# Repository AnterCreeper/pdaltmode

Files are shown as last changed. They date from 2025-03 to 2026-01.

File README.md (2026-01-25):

# USB PD Alt-mode Host-side Negotiation


If any questions, welcome for Issues & PRs   
如果有疑问，欢迎提交Issues或PR

**WARNING! This Project is not been fully long-term productive tested and without warranty of any kind, use at your own risk!**   
**警告！该项目未经充分的长期生产环境测试，作者不作任何保证，使用需要你自己衡量**

### License

This project is licensed under the LGPL-2.1-or-later license. **DO NOT** download or clone this project until you have read and agree the LICENSE.     
该项目采用 `LGPL-2.1 以及之后版本` 授权。当你下载或克隆项目时，默认已经阅读并同意该协定。

### TODO

1. Active Cable Support (not in plan)
2. Audio Transmission Function Testing

### Overview

This Project is used to perform PD Logic for Host-side based on the cost-effective (30 cents at the time of writing) WCH CH32X035 32-bit RISC-V microcontroller, to achieve DisplayPort output over Type-C, which can be used on space compact scene.    
该项目基于来自 WCH 的低成本 CH32X035 微控制器，包含了所需的所有主机端的 USB Power Delivery 协议的功能，以实现 Type-C 上 DisplayPort 视频输出功能，可用于 PCB 面积紧凑场景。

Besides, This Project include a validation hardware with GERBER and schematics, 4 layers JLC04081H-3313 Stacking, using TOSHIBA TC358867XBG to convert Video stream from Parallel to DisplayPort Signal.   
此外，该项目附有一个验证硬件，包含 GERBER 和原理图与装配图纸，四层 0.8mm JLC04081H-3313 叠层，采用 TOSHIBA TC358867XBG 将 RGB 并行接口 转换至 DisplayPort 信号输出。

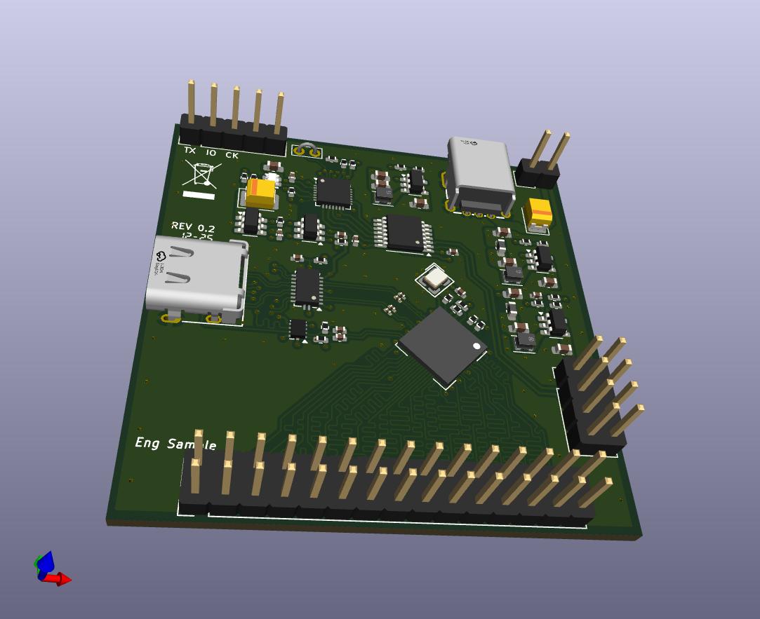
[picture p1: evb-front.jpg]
PCB Preview Picture


This Project implements state machines defined in:
1. Universal Serial Bus Power Delivery Specification Rev 2.0 Ver 1.3
2. Universal Serial Bus Type-C Cable and Connector Specification Ver 2.2.
3. VESA DisplayPort Alt Mode on USB Type-C Standard. Ver 1.3/1.4.
4. VESA DisplayPort Standard. Version 1, Revision 2.

Doc. 1 and 2 can be accessed from https://github.com/usb-c/USB-Type-C   
For Doc. 3, since **DISTRIBUTION TO NON-MEMBERS IS PROHIBITED**, contact me at [wangzhihao9@hotmail.com](mailto:wangzhihao9@hotmail.com)  
Doc.4 is located at https://glenwing.github.io/docs/DP-1.2.pdf

Datasheet of TC358867XBG is included in the project, which includes external LICENSE.

Some other Specification related to Audio which is needed: (May have copies over web.archive.org)
1. [CEA 861-E](https://members.cta.tech/ctaPublicationDetails/?id=95190170-1031-e811-bbd4-0003ff52999d): A DTV Profile for Uncompressed High Speed Digital Interfaces
2. [IEC60958](https://webstore.iec.ch/en/publication/62829): Digital Audio Interfaces

### Usage

1. Download and Open with MounRiver Studio II [Download Page](http://www.mounriver.com/download)
2. Connect the board with WCH Link-E, then Compile and Run
3. ~~Files except in User is remain unchanged from default.~~

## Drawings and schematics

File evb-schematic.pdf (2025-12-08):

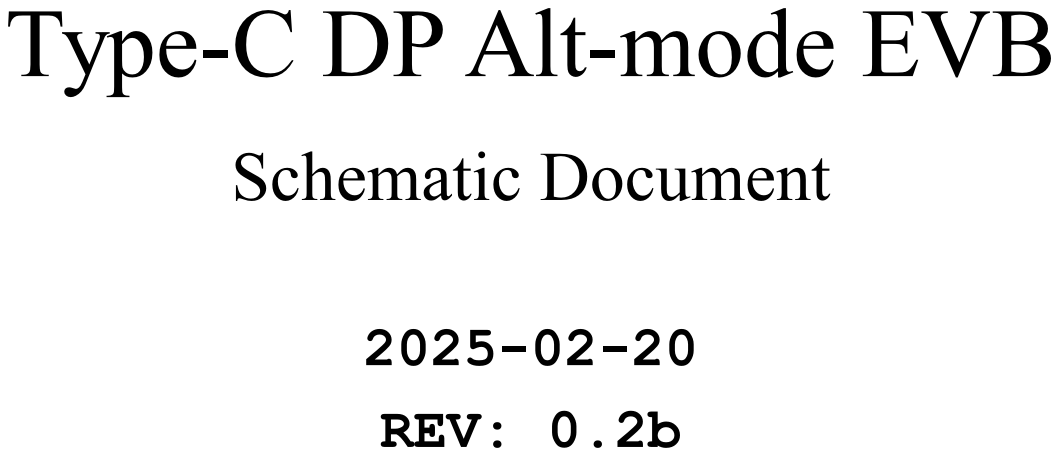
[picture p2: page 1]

Id: 1/5 Title: File: cover.kicad_sch Sheet: /COVER/ Type-CDPAlt-modeEVB
SchematicDocument

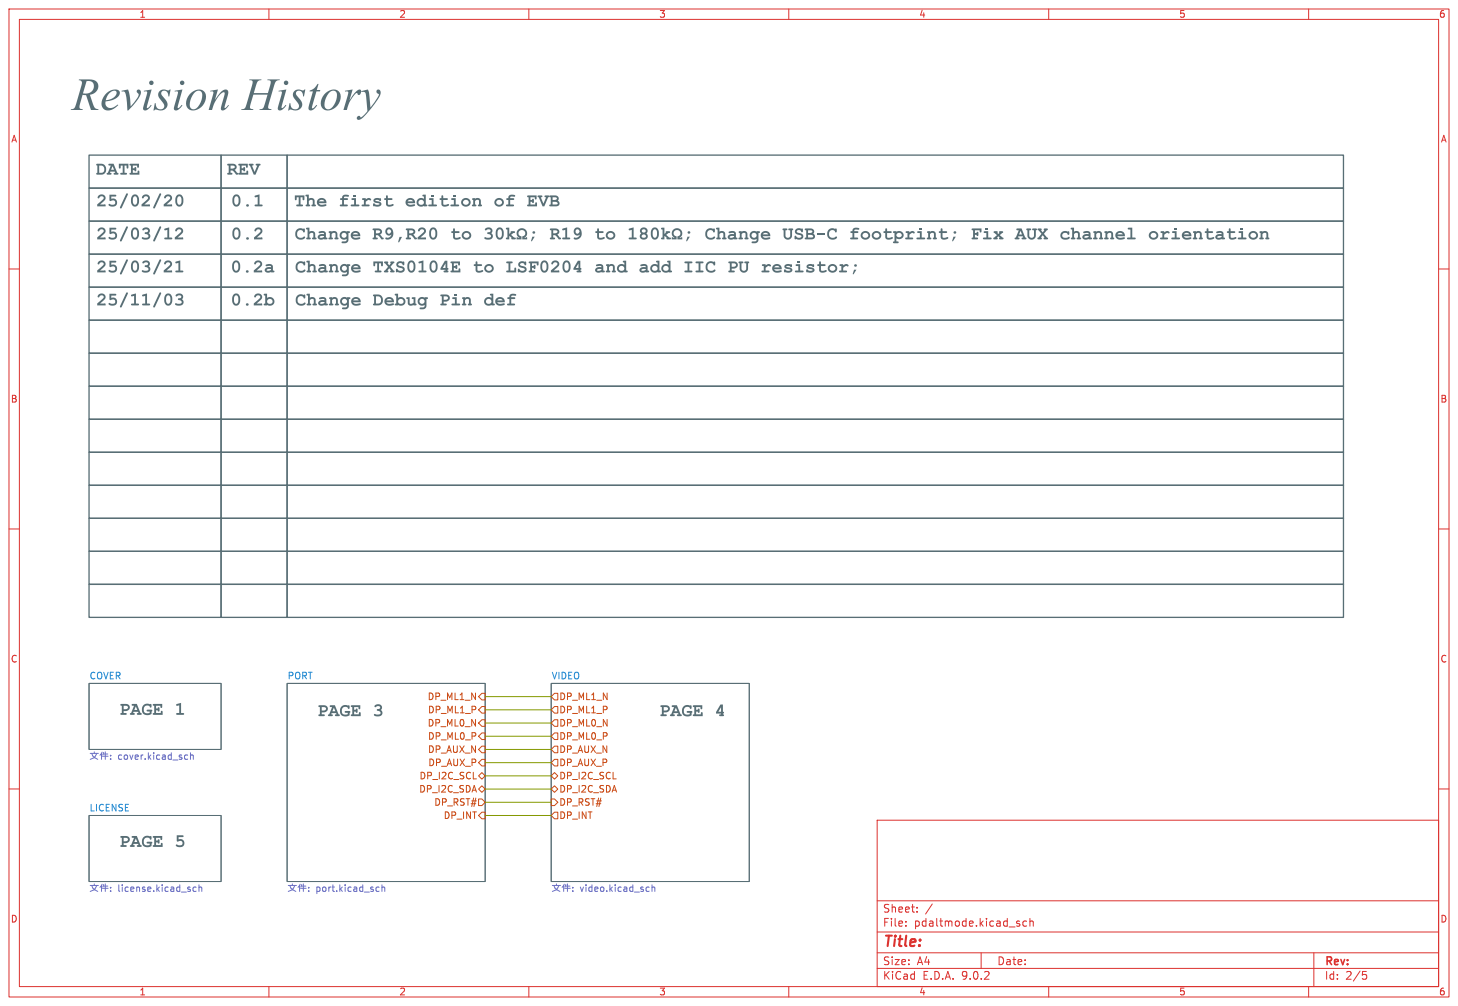
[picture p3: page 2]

DATE | REV
25/02/20 | 0.1 | The first edition of EVB
25/03/12 | 0.2 | Change R9,R20 to þÿ30k©; R19 to þÿ180k©; Change USB-C footprint; Fix AUX channel orientation
25/03/21 | 0.2a | Change TXS0104E to LSF0204 and add IIC PU resistor;
25/11/03 | 0.2b | Change Debug Pin def

þÿe‡Nö: license.kicad_sch COVER
PAGE 1

Id: 2/5 Title: File: pdaltmode.kicad_sch Sheet: / LICENSE
PAGE 5

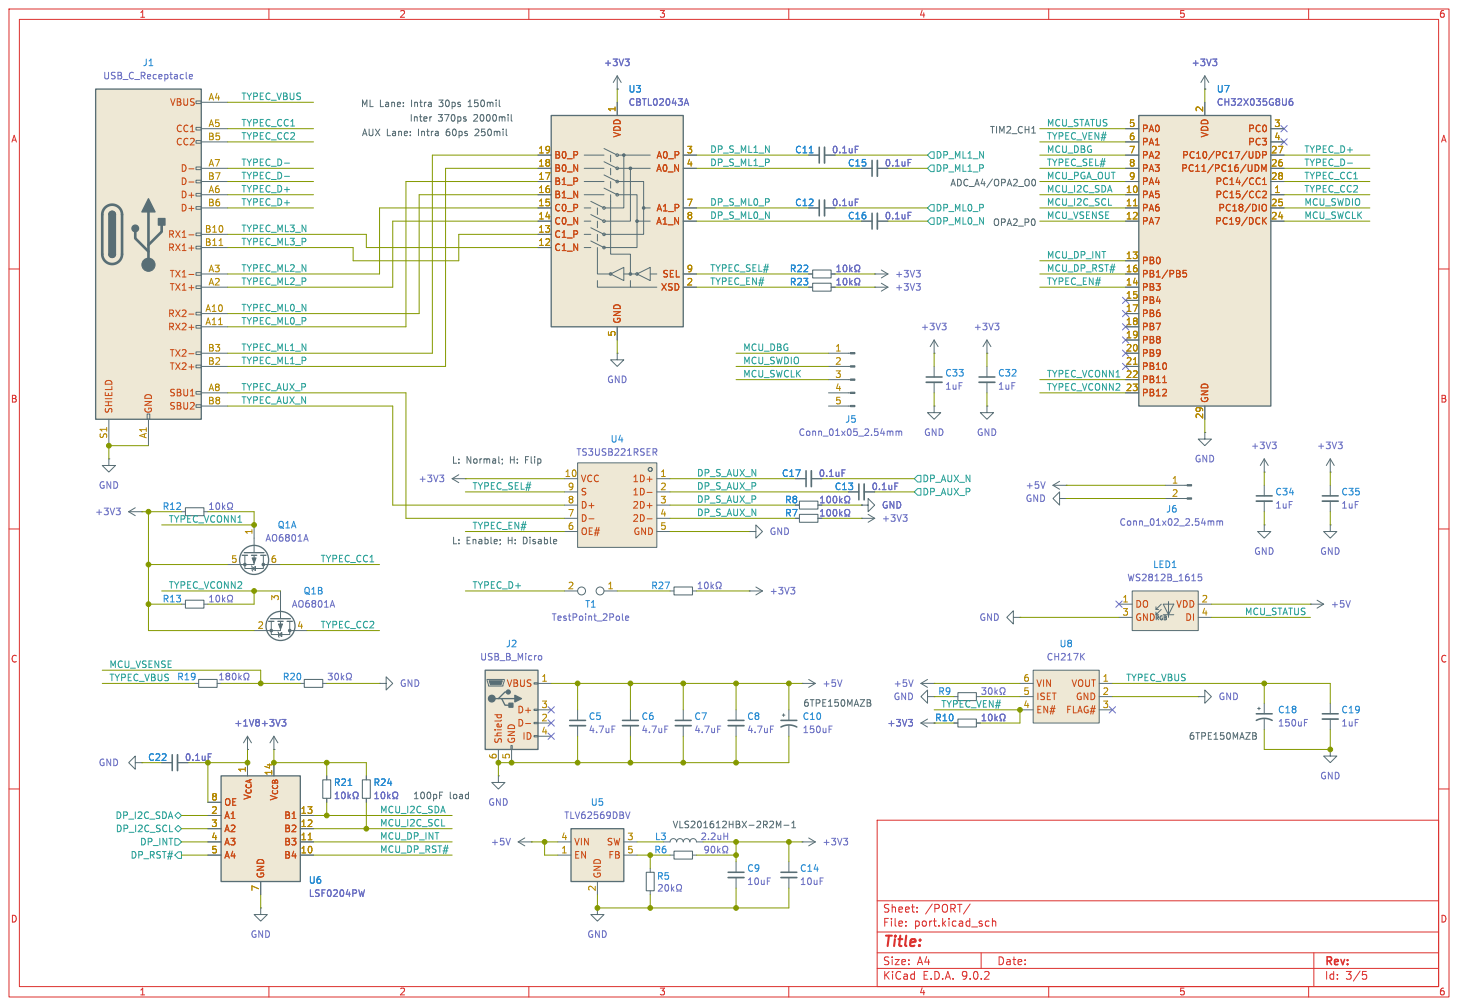
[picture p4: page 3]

L: Enable; H: Disable ML Lane: Intra 30ps 150mil Inter 370ps 2000mil AUX Lane: Intra 60ps 250mil L: Normal; H: Flip

2 GND 29 PC0 3 PC3 4 PC10/PC17/UDP 27 PC11/PC16/UDM 26 PC14/CC1 28 PC15/CC2 1 PC18/DIO 25 PC19/DCK 24 PB1/PB5 16 +3V3 R10 þÿ10k©

2 GND 29 PC0 3 PC3 4 PC10/PC17/UDP 27 PC11/PC16/UDM 26 PC14/CC1 28 PC15/CC2 1 PC18/DIO 25 PC19/DCK 24 PB1/PB5 16 U7 CH32X035G8U6

2 SW 3 FB 5 U5 TLV62569DBV R13 þÿ10k© GND

6TPE150MAZB
Id: 3/5 Title: File: port.kicad_sch Sheet: /PORT/ C10

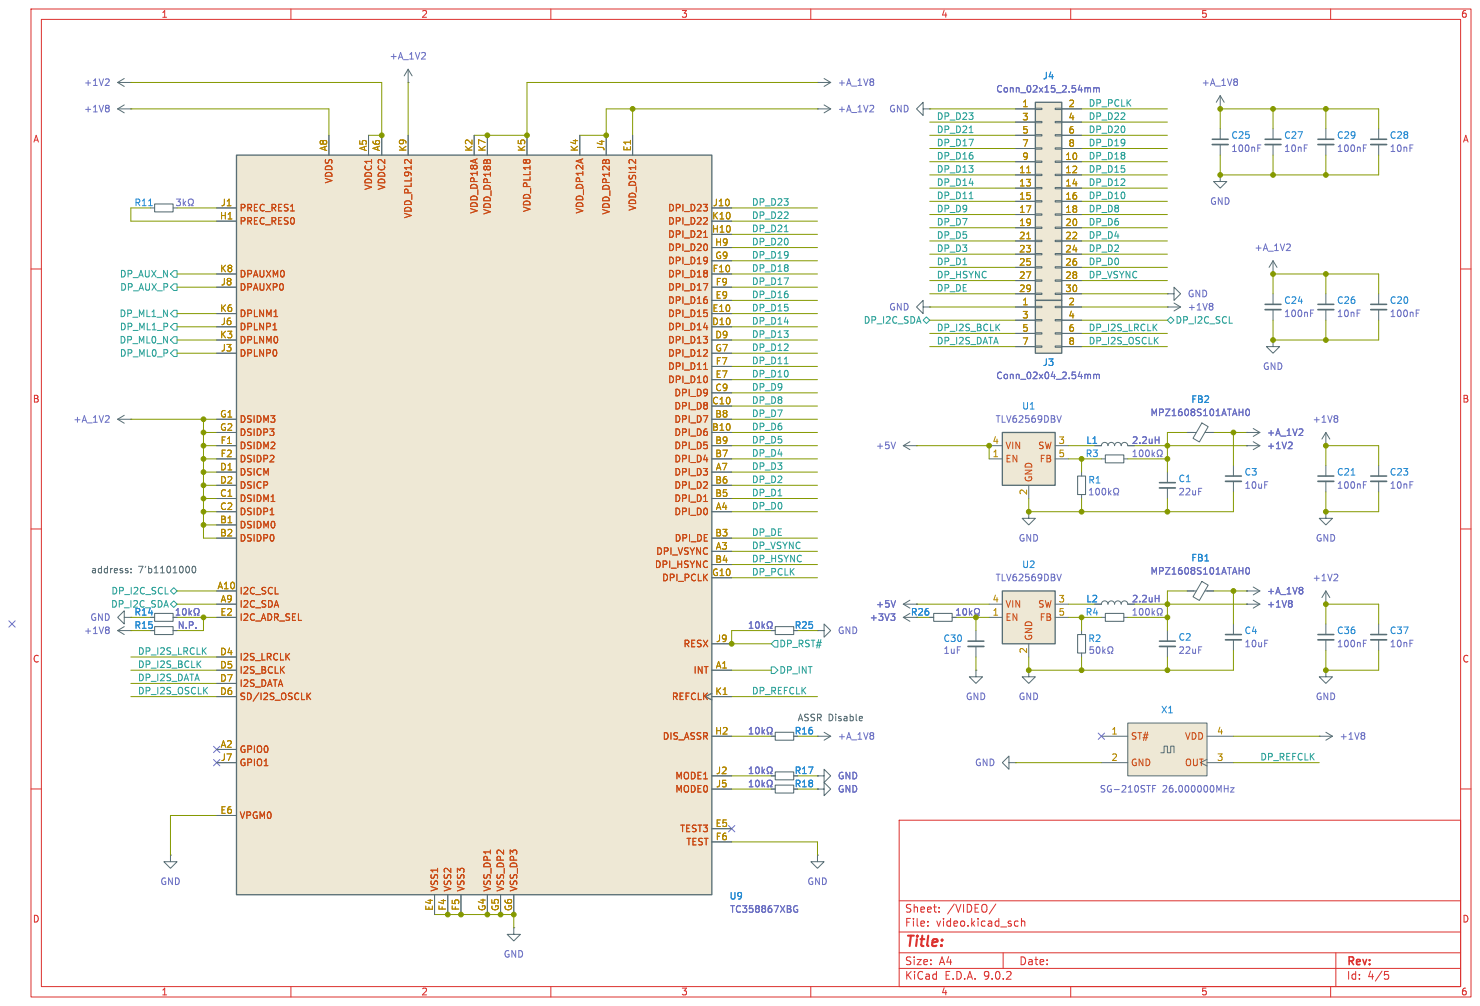
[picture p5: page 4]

2 SW 3 FB 5 U2 TLV62569DBV GND GND

Id: 4/5 Title: File: video.kicad_sch Sheet: /VIDEO/

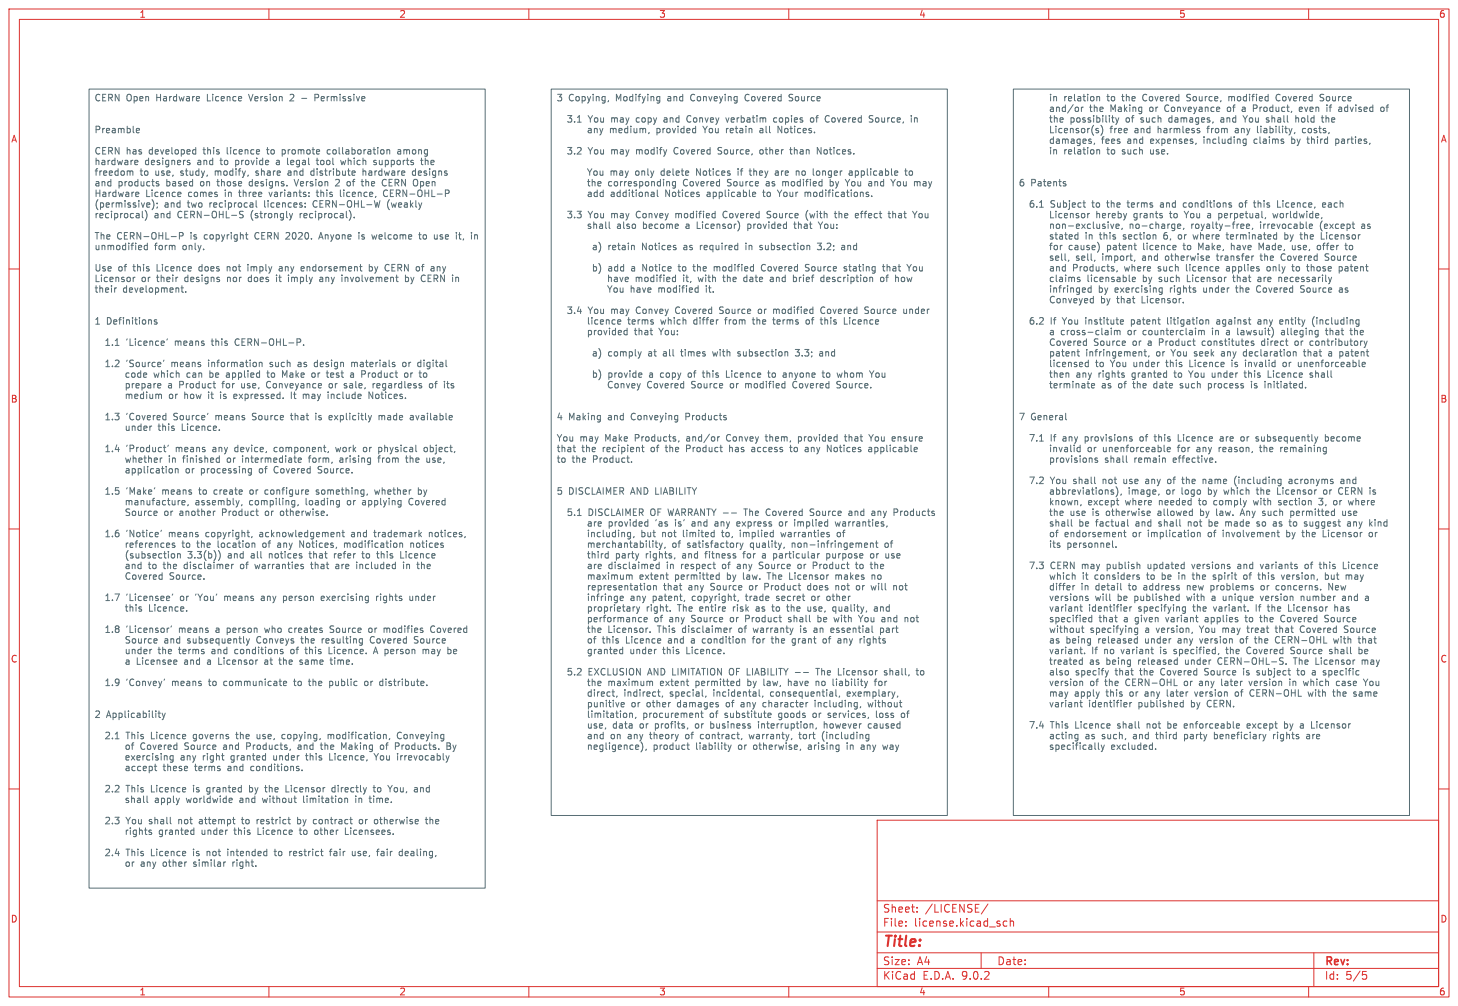
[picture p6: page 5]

for cause) patent licence to Make, have Made, use, offer to

licence terms which differ from the terms of this Licence

to the Product. 5 DISCLAIMER AND LIABILITY

known, except where needed to comply with section 3, or where

version of the CERN-OHL or any later version in which case You may apply this or any later version of CERN-OHL with the same

Id: 5/5 Title: File: license.kicad_sch Sheet: /LICENSE/

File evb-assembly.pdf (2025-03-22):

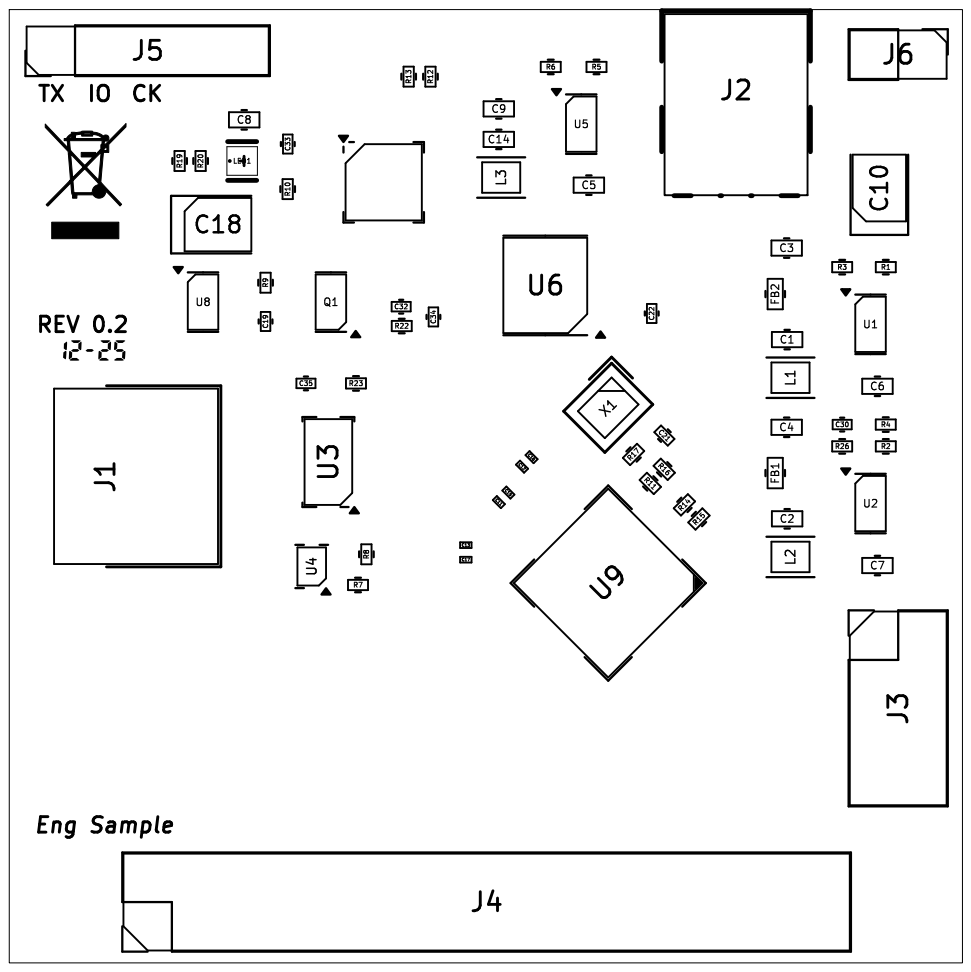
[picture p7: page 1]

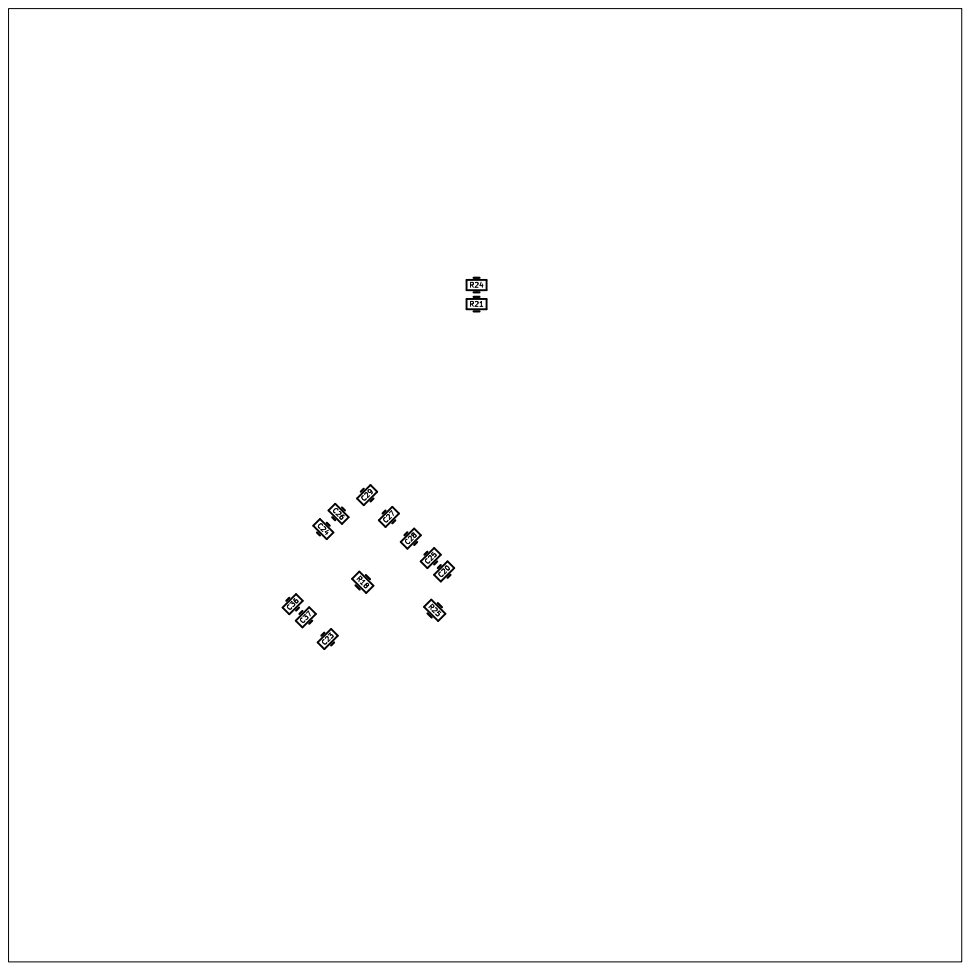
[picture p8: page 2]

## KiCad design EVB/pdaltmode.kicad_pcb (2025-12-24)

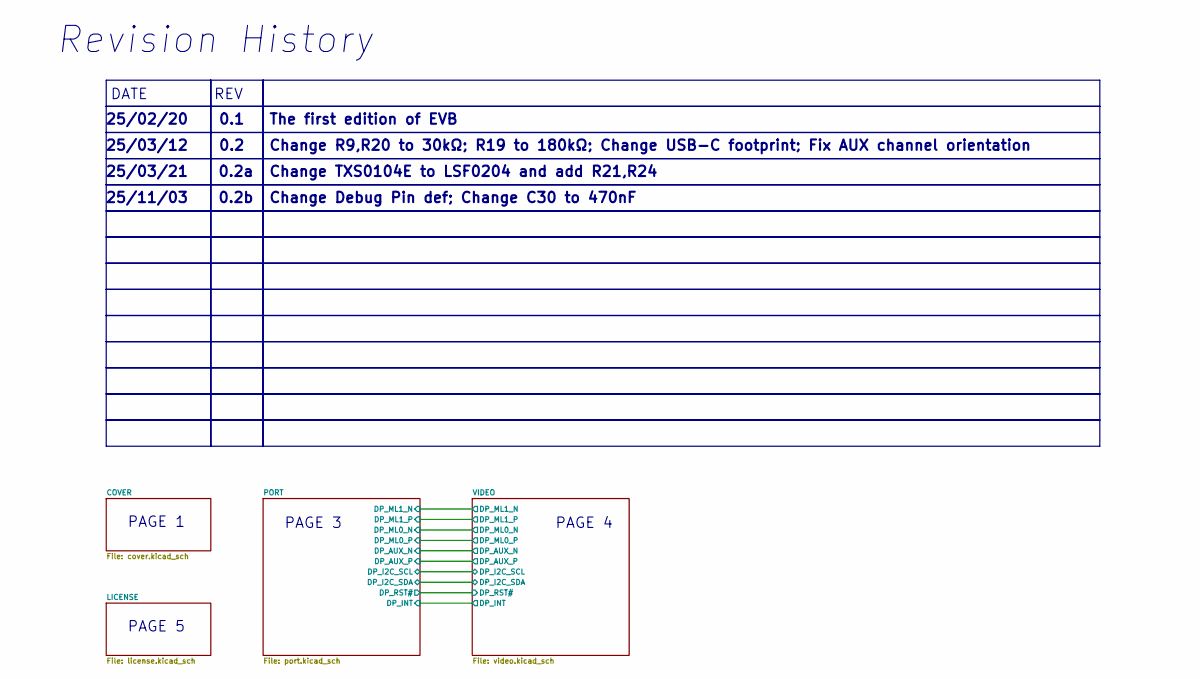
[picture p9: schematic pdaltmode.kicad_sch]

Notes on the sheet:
Change Debug Pin def; Change C30 to 470nF
Change TXS0104E to LSF0204 and add R21,R24
PAGE 5
25/11/03
PAGE 3
PAGE 1
0.2b
Change R9,R20 to 30kΩ; R19 to 180kΩ; Change USB-C footprint; Fix AUX channel orientation
0.1
Revision History
The first edition of EVB
DATE
25/03/12
0.2a
0.2
25/03/21
PAGE 4
REV
25/02/20

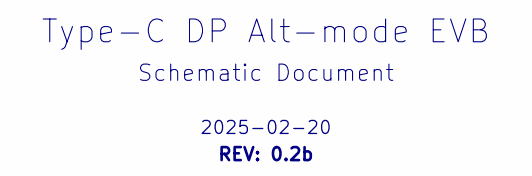
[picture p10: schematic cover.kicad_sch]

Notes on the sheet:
REV: 0.2b
2025-02-20
Type-C DP Alt-mode EVB
Schematic Document

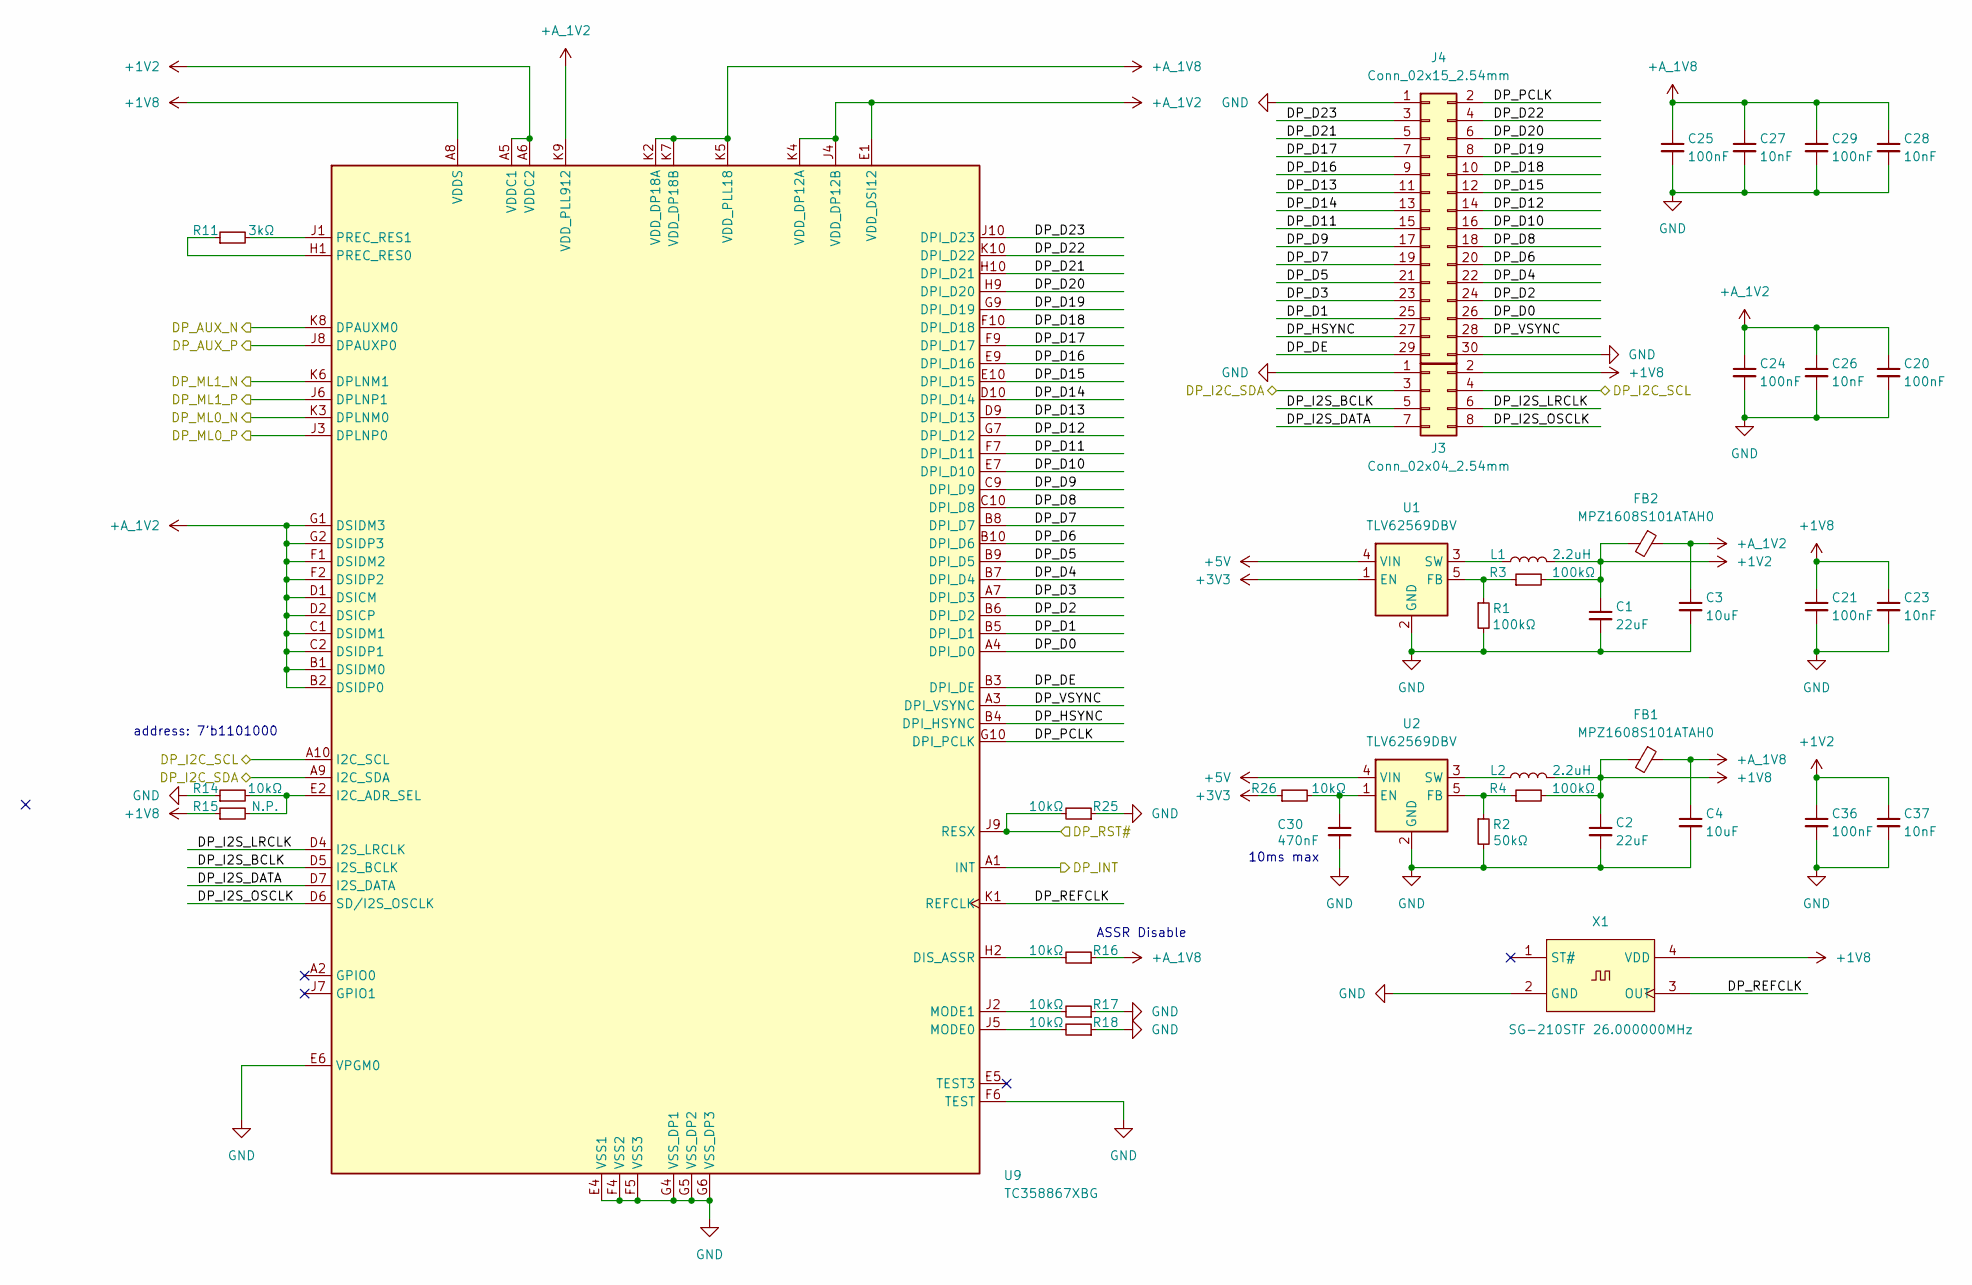
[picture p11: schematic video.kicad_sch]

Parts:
C1, C2: 22uF; C_0603_1608Metric
C3, C4: 10uF; C_0603_1608Metric
C20, C21, C24, C25, C29, C36: 100nF; C_0402_1005Metric
C23, C26, C27, C28, C37: 10nF; C_0402_1005Metric
C30: 470nF; C_0402_1005Metric
FB1, FB2: MPZ1608S101ATAH0; L_0603_1608Metric
J3: Conn_02x04_2.54mm; PinHeader_2x04_P2.54mm_Vertical
J4: Conn_02x15_2.54mm; PinHeader_2x15_P2.54mm_Vertical
L1, L2: 2.2uH; L_Murata_DFE201610P
R1, R3, R4: 100kΩ; R_0402_1005Metric
R2: 50kΩ; R_0402_1005Metric
R11: 3kΩ; R_0402_1005Metric
R14, R16, R17, R18, R25, R26: 10kΩ; R_0402_1005Metric
R15: N.P.; R_0402_1005Metric
U1, U2: TLV62569DBV; SOT-23-5
U9: TC358867XBG; Toshiba_VFBGA-80_7.0x7.0mm
X1: SG-210STF 26.000000MHz; Oscillator_SMD_SeikoEpson_SG210-4Pin_2.5x2.0mm

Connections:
+1V2: C1.1, C36.1, C37.1, FB2.2, L1.2, R3.2, U9.A5 (VDDC1), U9.A6 (VDDC2)
+1V8: C2.1, C21.1, C23.1, FB1.2, J3.2, L2.2, R4.2, R15.1, U9.A8 (VDDS), X1.4 (VDD); also elsewhere on the board
+3V3: R26.1, U1.1 (EN); also elsewhere on the board
+5V: U1.4 (VIN), U2.4 (VIN); also elsewhere on the board
+A_1V2: C3.1, C20.1, C24.1, C26.1, FB2.1, U9.B1 (DSIDM0), U9.B2 (DSIDP0), U9.C1 (DSIDM1), U9.C2 (DSIDP1), U9.D1 (DSICM), U9.D2 (DSICP), U9.E1 (VDD_DSI12), U9.F1 (DSIDM2), U9.F2 (DSIDP2), U9.G1 (DSIDM3), U9.G2 (DSIDP3), U9.J4 (VDD_DP12B), U9.K4 (VDD_DP12A), U9.K9 (VDD_PLL912)
+A_1V8: C4.1, C25.1, C27.1, C28.1, C29.1, FB1.1, R16.1, U9.K2 (VDD_DP18A), U9.K5 (VDD_PLL18), U9.K7 (VDD_DP18B)
/PORT/DP_AUX_N: U9.K8 (DPAUXM0); also elsewhere on the board
/PORT/DP_AUX_P: U9.J8 (DPAUXP0); also elsewhere on the board
/PORT/DP_I2C_SCL: J3.4, U9.A10 (I2C_SCL); also elsewhere on the board
/PORT/DP_I2C_SDA: J3.3, U9.A9 (I2C_SDA); also elsewhere on the board
/PORT/DP_INT: U9.A1 (INT); also elsewhere on the board
/PORT/DP_ML0_N: U9.K3 (DPLNM0); also elsewhere on the board
/PORT/DP_ML0_P: U9.J3 (DPLNP0); also elsewhere on the board
/PORT/DP_ML1_N: U9.K6 (DPLNM1); also elsewhere on the board
/PORT/DP_ML1_P: U9.J6 (DPLNP1); also elsewhere on the board
/PORT/DP_RST#: R25.2, U9.J9 (RESX); also elsewhere on the board
/VIDEO/DP_D0: J4.26, U9.A4 (DPI_D0)
/VIDEO/DP_D1: J4.25, U9.B5 (DPI_D1)
/VIDEO/DP_D2: J4.24, U9.B6 (DPI_D2)
/VIDEO/DP_D3: J4.23, U9.A7 (DPI_D3)
/VIDEO/DP_D4: J4.22, U9.B7 (DPI_D4)
/VIDEO/DP_D5: J4.21, U9.B9 (DPI_D5)
/VIDEO/DP_D6: J4.20, U9.B10 (DPI_D6)
/VIDEO/DP_D7: J4.19, U9.B8 (DPI_D7)
/VIDEO/DP_D8: J4.18, U9.C10 (DPI_D8)
/VIDEO/DP_D9: J4.17, U9.C9 (DPI_D9)
/VIDEO/DP_D10: J4.16, U9.E7 (DPI_D10)
/VIDEO/DP_D11: J4.15, U9.F7 (DPI_D11)
/VIDEO/DP_D12: J4.14, U9.G7 (DPI_D12)
/VIDEO/DP_D13: J4.11, U9.D9 (DPI_D13)
/VIDEO/DP_D14: J4.13, U9.D10 (DPI_D14)
/VIDEO/DP_D15: J4.12, U9.E10 (DPI_D15)
/VIDEO/DP_D16: J4.9, U9.E9 (DPI_D16)
/VIDEO/DP_D17: J4.7, U9.F9 (DPI_D17)
/VIDEO/DP_D18: J4.10, U9.F10 (DPI_D18)
/VIDEO/DP_D19: J4.8, U9.G9 (DPI_D19)
/VIDEO/DP_D20: J4.6, U9.H9 (DPI_D20)
/VIDEO/DP_D21: J4.5, U9.H10 (DPI_D21)
/VIDEO/DP_D22: J4.4, U9.K10 (DPI_D22)
/VIDEO/DP_D23: J4.3, U9.J10 (DPI_D23)
/VIDEO/DP_DE: J4.29, U9.B3 (DPI_DE)
/VIDEO/DP_HSYNC: J4.27, U9.B4 (DPI_HSYNC)
/VIDEO/DP_I2S_BCLK: J3.5, U9.D5 (I2S_BCLK)
/VIDEO/DP_I2S_DATA: J3.7, U9.D7 (I2S_DATA)
/VIDEO/DP_I2S_LRCLK: J3.6, U9.D4 (I2S_LRCLK)
/VIDEO/DP_I2S_OSCLK: J3.8, U9.D6 (SD/I2S_OSCLK)
/VIDEO/DP_PCLK: J4.2, U9.G10 (DPI_PCLK)
/VIDEO/DP_REFCLK: U9.K1 (REFCLK), X1.3 (OUT)
/VIDEO/DP_VSYNC: J4.28, U9.A3 (DPI_VSYNC)
GND: C1.2, C2.2, C3.2, C4.2, C20.2, C21.2, C23.2, C24.2, C25.2, C26.2, C27.2, C28.2, C29.2, C30.2, C36.2, C37.2, J3.1, J4.1, J4.30, R1.2, R2.2, R14.1, R17.1, R18.1, R25.1, U1.2 (GND), U2.2 (GND), U9.E4 (VSS1), U9.E6 (VPGM0), U9.F4 (VSS2), U9.F5 (VSS3), U9.F6 (TEST), U9.G4 (VSS_DP1), U9.G5 (VSS_DP2), U9.G6 (VSS_DP3), X1.2 (GND); also elsewhere on the board
unnamed: R1.1, R3.1, U1.5 (FB)
unnamed: L1.1, U1.3 (SW)
unnamed: C30.1, R26.2, U2.1 (EN)
unnamed: R2.1, R4.1, U2.5 (FB)
unnamed: L2.1, U2.3 (SW)
unnamed: R16.2, U9.H2 (DIS_ASSR)
unnamed: R14.2, R15.2, U9.E2 (I2C_ADR_SEL)
unnamed: R18.2, U9.J5 (MODE0)
unnamed: R17.2, U9.J2 (MODE1)
unnamed: R11.1, U9.H1 (PREC_RES0)
unnamed: R11.2, U9.J1 (PREC_RES1)

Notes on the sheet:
ASSR Disable
10ms max
address: 7'b1101000

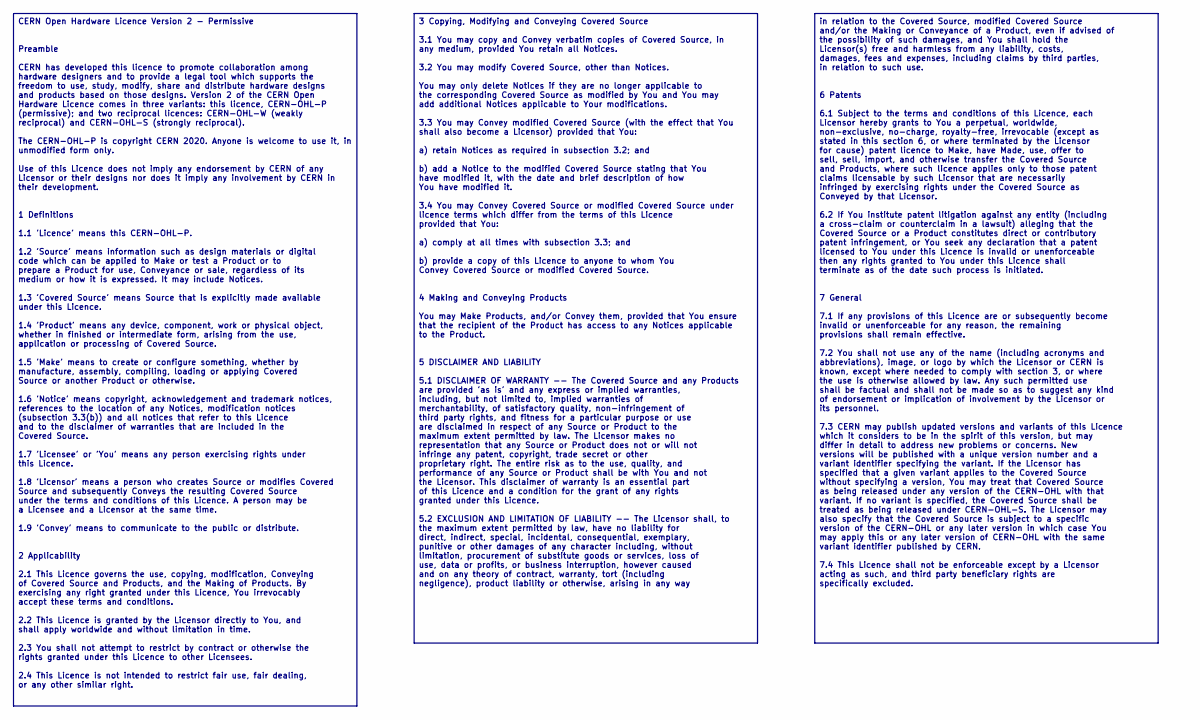
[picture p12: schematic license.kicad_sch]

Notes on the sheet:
3 Copying, Modifying and Conveying Covered Source 3.1 You may copy and Convey verbatim copies of Covered Source, in any medium, provided You retain all Notices. 3.2 You may modify Covered Source, other than Notices. You may only delete Notices if they are no longer applicable to the corresponding C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
CERN Open Hardware Licence Version 2 - Permissive Preamble CERN has developed this licence to promote collaboration among hardware designers and to provide a legal tool which supports the freedom to use, study, modify, share and distribute hardware designs and products based on those designs. Versi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
in relation to the Covered Source, modified Covered Source and/or the Making or Conveyance of a Product, even if advised of the possibility of such damages, and You shall hold the Licensor(s) free and harmless from any liability, costs, damages, fees and expenses, including claims by third parties,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

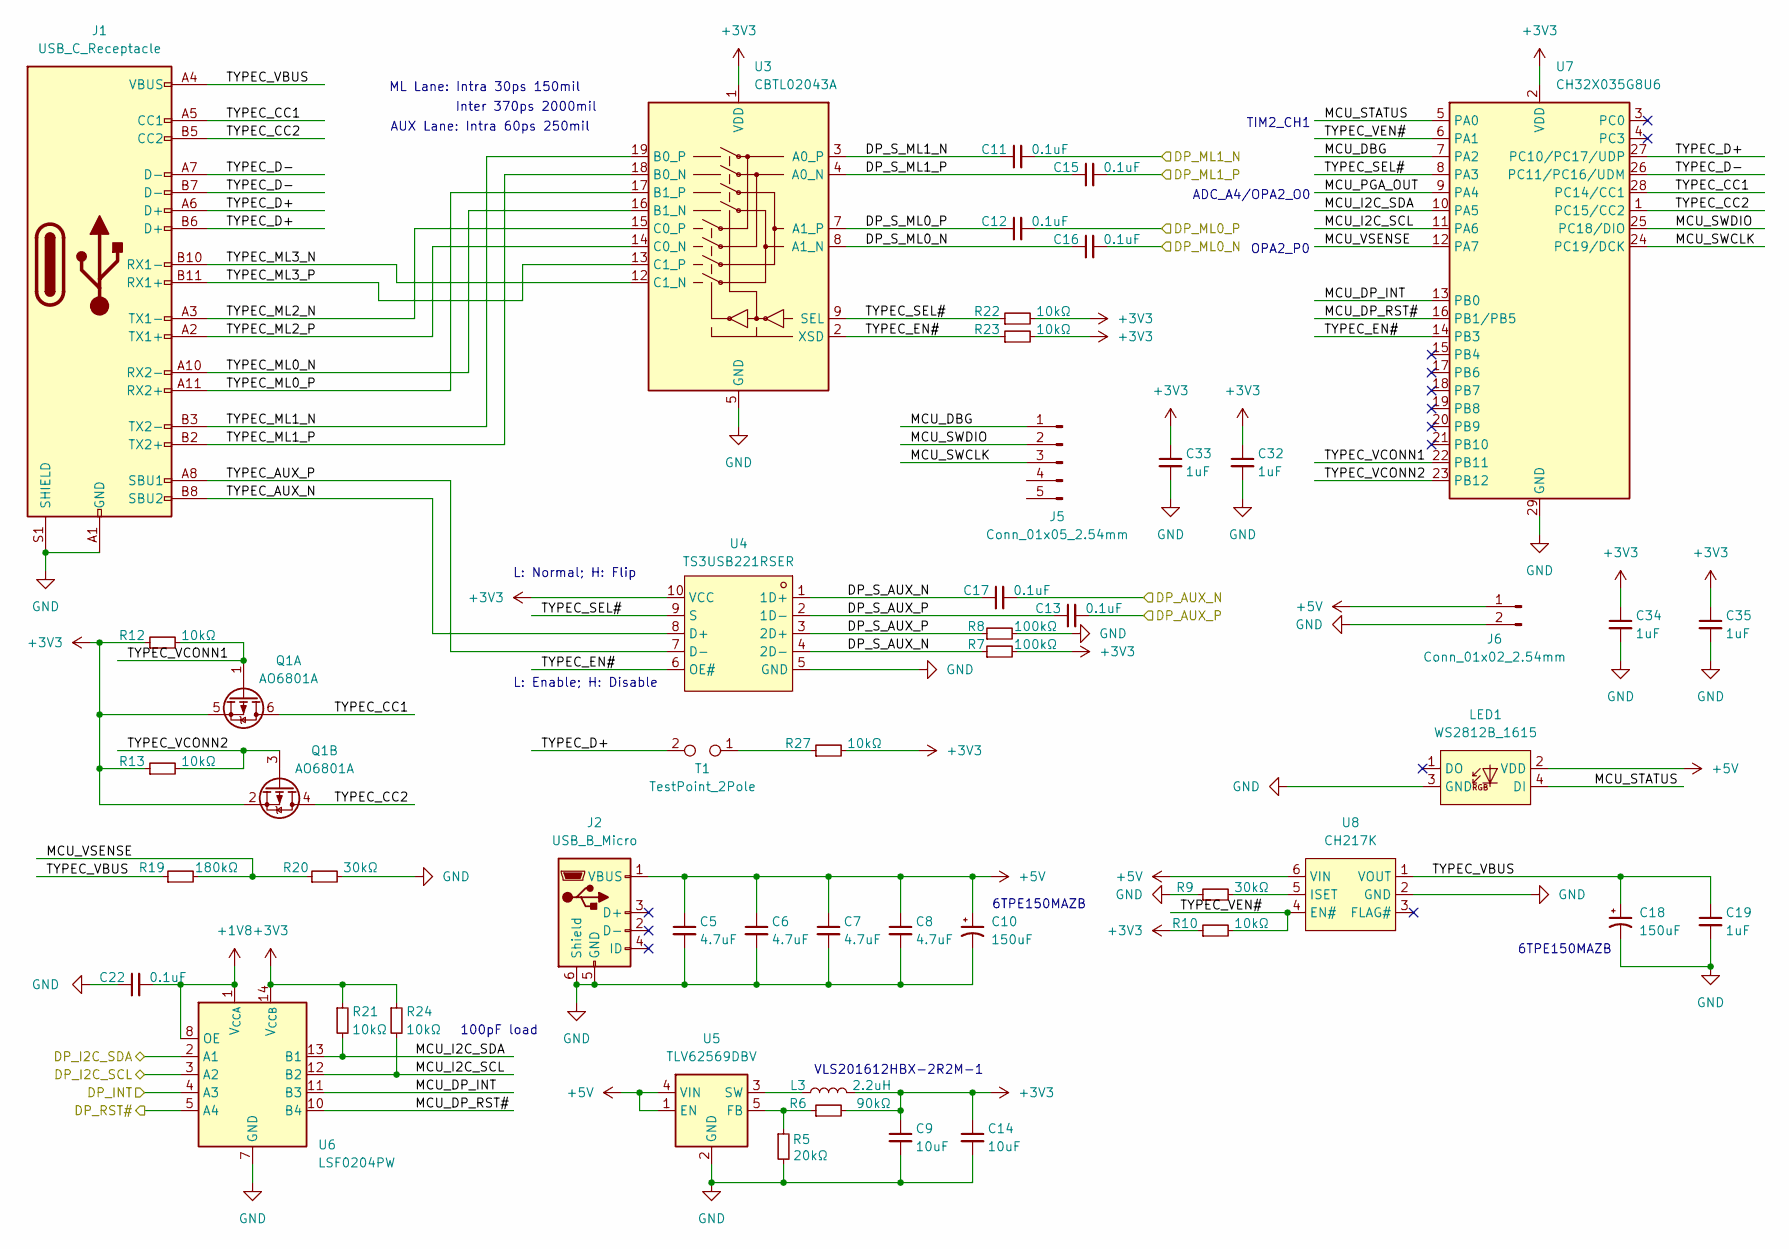
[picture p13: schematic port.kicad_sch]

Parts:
C5, C6, C7, C8: 4.7uF; C_0603_1608Metric
C9, C14: 10uF; C_0603_1608Metric
C10, C18: 150uF; CP_EIA-3528-21_Kemet-B
C11, C12, C15, C16: 0.1uF; C_0201_0603Metric
C13, C17, C22: 0.1uF; C_0402_1005Metric
C19, C32, C33, C34, C35: 1uF; C_0402_1005Metric
J1: USB_C_Receptacle; USB_C_Receptacle_Amphenol_10137062-00021LF
J2: USB_B_Micro; USB_Mini-B_Wuerth_651005136521
J5: Conn_01x05_2.54mm; PinHeader_1x05_P2.54mm_Vertical
J6: Conn_01x02_2.54mm; PinHeader_1x02_P2.54mm_Vertical
L3: 2.2uH; L_Murata_DFE201610P
LED1: WS2812B_1615; LED_WS2812B-1615_SMD-4P_1.6x1.5mm; LCSC Part Name XL-1615RGBC-WS2812B-S
Q1: AO6801A; SOT-23-6
R5: 20kΩ; R_0402_1005Metric
R6: 90kΩ; R_0402_1005Metric
R7, R8: 100kΩ; R_0402_1005Metric
R9, R20: 30kΩ; R_0402_1005Metric
R10, R12, R13, R21, R22, R23, R24, R27: 10kΩ; R_0402_1005Metric
R19: 180kΩ; R_0402_1005Metric
T1: TestPoint_2Pole; TestPoint_Bridge_Pitch2.0mm_Drill0.7mm
U3: CBTL02043A; WQFN-20-1EP_2.5x4.5mm_P0.5mm_EP1x2.9mm
U4: TS3USB221RSER; Texas_UQFN-10_1.5x2mm_P0.5mm
U5: TLV62569DBV; SOT-23-5
U6: LSF0204PW; TSSOP-14_4.4x5mm_P0.65mm
U7: CH32X035G8U6; QFN-28-1EP_4x4mm_P0.4mm_EP2.7x2.7mm
U8: CH217K; SOT-23-6

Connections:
+1V8: C22.2, U6.1 (V_{CCA}), U6.8 (OE); also elsewhere on the board
+3V3: C9.1, C14.1, C32.1, C33.1, C34.1, C35.1, L3.2, Q1.2 (S), Q1.5 (S), R6.2, R7.2, R10.1, R12.1, R13.1, R21.1, R22.2, R23.2, R24.1, R27.2, U3.1 (VDD), U3.6 (VDD), U3.10 (VDD), U4.10 (VCC), U6.14 (V_{CCB}), U7.2 (VDD); also elsewhere on the board
+5V: C5.1, C6.1, C7.1, C8.1, C10.1, J2.1 (VBUS), J6.1, LED1.2 (VDD), U5.1 (EN), U5.4 (VIN), U8.6 (VIN); also elsewhere on the board
/PORT/DP_AUX_N: C17.2; also elsewhere on the board
/PORT/DP_AUX_P: C13.2; also elsewhere on the board
/PORT/DP_I2C_SCL: U6.3 (A2); also elsewhere on the board
/PORT/DP_I2C_SDA: U6.2 (A1); also elsewhere on the board
/PORT/DP_INT: U6.4 (A3); also elsewhere on the board
/PORT/DP_ML0_N: C16.2; also elsewhere on the board
/PORT/DP_ML0_P: C12.2; also elsewhere on the board
/PORT/DP_ML1_N: C11.2; also elsewhere on the board
/PORT/DP_ML1_P: C15.2; also elsewhere on the board
/PORT/DP_RST#: U6.5 (A4); also elsewhere on the board
/PORT/DP_S_AUX_N: C17.1, R7.1, U4.1 (1D+), U4.4 (2D-)
/PORT/DP_S_AUX_P: C13.1, R8.1, U4.2 (1D-), U4.3 (2D+)
/PORT/DP_S_ML0_N: C16.1, U3.8 (A1_N)
/PORT/DP_S_ML0_P: C12.1, U3.7 (A1_P)
/PORT/DP_S_ML1_N: C11.1, U3.3 (A0_P)
/PORT/DP_S_ML1_P: C15.1, U3.4 (A0_N)
/PORT/MCU_DBG: J5.1, U7.7 (PA2)
/PORT/MCU_DP_INT: U6.11 (B3), U7.13 (PB0)
/PORT/MCU_DP_RST#: U6.10 (B4), U7.16 (PB1/PB5)
/PORT/MCU_I2C_SCL: R24.2, U6.12 (B2), U7.11 (PA6)
/PORT/MCU_I2C_SDA: R21.2, U6.13 (B1), U7.10 (PA5)
/PORT/MCU_PGA_OUT: U7.9 (PA4)
/PORT/MCU_STATUS: LED1.4 (DI), U7.5 (PA0)
/PORT/MCU_SWCLK: J5.3, U7.24 (PC19/DCK)
/PORT/MCU_SWDIO: J5.2, U7.25 (PC18/DIO)
/PORT/MCU_VSENSE: R19.2, R20.1, U7.12 (PA7)
/PORT/TYPEC_AUX_N: J1.B8 (SBU2), U4.8 (D+)
/PORT/TYPEC_AUX_P: J1.A8 (SBU1), U4.7 (D-)
/PORT/TYPEC_CC1: J1.A5 (CC1), Q1.6 (D), U7.28 (PC14/CC1)
/PORT/TYPEC_CC2: J1.B5 (CC2), Q1.4 (D), U7.1 (PC15/CC2)
/PORT/TYPEC_D+: J1.A6 (D+), J1.B6 (D+), T1.2, U7.27 (PC10/PC17/UDP)
/PORT/TYPEC_D-: J1.A7 (D-), J1.B7 (D-), U7.26 (PC11/PC16/UDM)
/PORT/TYPEC_EN#: R23.1, U3.2 (XSD), U4.6 (OE#), U7.14 (PB3)
/PORT/TYPEC_ML0_N: J1.A10 (RX2-), U3.16 (B1_N)
/PORT/TYPEC_ML0_P: J1.A11 (RX2+), U3.17 (B1_P)
/PORT/TYPEC_ML1_N: J1.B3 (TX2-), U3.19 (B0_P)
/PORT/TYPEC_ML1_P: J1.B2 (TX2+), U3.18 (B0_N)
/PORT/TYPEC_ML2_N: J1.A3 (TX1-), U3.15 (C0_P)
/PORT/TYPEC_ML2_P: J1.A2 (TX1+), U3.14 (C0_N)
/PORT/TYPEC_ML3_N: J1.B10 (RX1-), U3.12 (C1_N)
/PORT/TYPEC_ML3_P: J1.B11 (RX1+), U3.13 (C1_P)
/PORT/TYPEC_SEL#: R22.1, U3.9 (SEL), U4.9 (S), U7.8 (PA3)
/PORT/TYPEC_VBUS: C18.1, C19.1, J1.A4 (VBUS), J1.A9 (VBUS), J1.B4 (VBUS), J1.B9 (VBUS), R19.1, U8.1 (VOUT)
/PORT/TYPEC_VCONN1: Q1.1 (G), R12.2, U7.22 (PB11)
/PORT/TYPEC_VCONN2: Q1.3 (G), R13.2, U7.23 (PB12)
/PORT/TYPEC_VEN#: R10.2, U7.6 (PA1), U8.4 (EN#)
GND: C5.2, C6.2, C7.2, C8.2, C9.2, C10.2, C14.2, C18.2, C19.2, C22.1, C32.2, C33.2, C34.2, C35.2, J1.A1 (GND), J1.A12 (GND), J1.B1 (GND), J1.B12 (GND), J1.S1 (SHIELD), J2.5 (GND), J2.6 (Shield), J6.2, LED1.3 (GND), R5.2, R8.2, R9.1, R20.2, U3.5 (GND), U3.11 (GND), U3.20 (GND), U3.21 (GND), U4.5 (GND), U5.2 (GND), U6.7 (GND), U7.29 (GND), U8.2 (GND); also elsewhere on the board
unnamed: R27.1, T1.1
unnamed: R5.1, R6.1, U5.5 (FB)
unnamed: L3.1, U5.3 (SW)
unnamed: R9.2, U8.5 (ISET)

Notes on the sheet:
TIM2_CH1
6TPE150MAZB
AUX Lane: Intra 60ps 250mil
VLS201612HBX-2R2M-1
Inter 370ps 2000mil
OPA2_P0
100pF load
L: Enable; H: Disable
ADC_A4/OPA2_O0
ML Lane: Intra 30ps 150mil
L: Normal; H: Flip

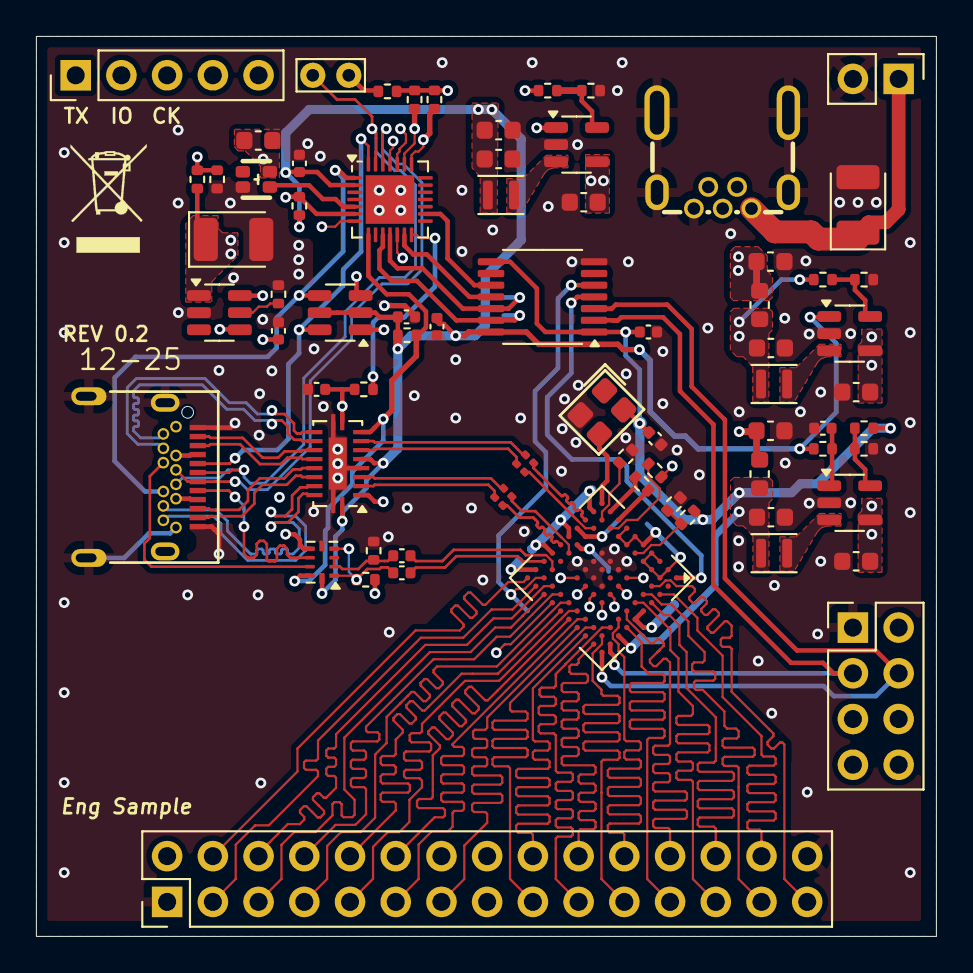
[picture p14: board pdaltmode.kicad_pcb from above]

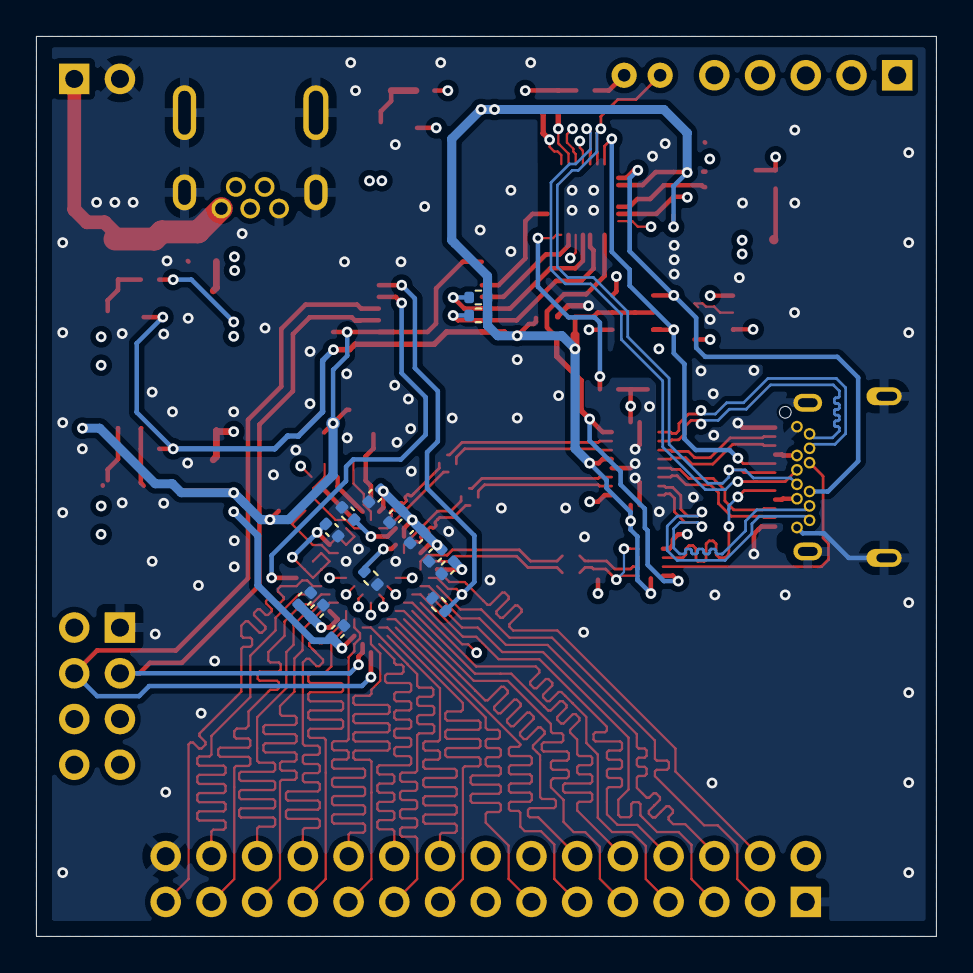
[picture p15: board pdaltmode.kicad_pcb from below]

Board: 4 copper layers, 50.0 x 50.0 mm, 87 parts (14 on the bottom side), 100 nets.

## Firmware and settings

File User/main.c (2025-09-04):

//#define IGNORE_HPD
//#define NO_MPD
//#define FORCE_SOFTMUL
#define FLIP_SEL 0    //reverse type-c mux select signal, debug only and set 0 for normal

#include "timer.h"
#include "sys.h"
#include "gpio.h"
#include "ws2812.h"
#include "iic.h"
#include "mpd.h"
#include "usbpd.h"
#include "debug.h"
#include <ch32x035_opa.h>

void VSNS_INIT() {
    GPIO_IN_INIT(GPIOA, GPIO_Pin_7);
    GPIO_Analog_INIT(GPIOA, GPIO_Pin_4);

    OPA_Unlock();
    OPA_InitTypeDef OPA_InitStructure = {0};
    OPA_InitStructure.OPA_NUM = OPA2;
    OPA_InitStructure.PSEL = CHP0;
    OPA_InitStructure.NSEL = CHN_PGA_4xIN;
    OPA_InitStructure.Mode = OUT_IO_OUT0;
    OPA_InitStructure.FB = FB_ON;
    OPA_Init(&OPA_InitStructure);
    OPA_Cmd(OPA2, ENABLE);
    printf("Enable OPA\r\n");

    RCC_APB2PeriphClockCmd(RCC_APB2Periph_ADC1, ENABLE);
    ADC_DeInit(ADC1);
    ADC_CLKConfig(ADC1, ADC_CLK_Div4);
    ADC_InitTypeDef ADC_InitStructure = {0};
    ADC_InitStructure.ADC_Mode = ADC_Mode_Independent;
    ADC_InitStructure.ADC_ScanConvMode = DISABLE;
    ADC_InitStructure.ADC_ContinuousConvMode = DISABLE;
    ADC_InitStructure.ADC_ExternalTrigConv = ADC_ExternalTrigConv_None;
    ADC_InitStructure.ADC_DataAlign = ADC_DataAlign_Right;
    ADC_InitStructure.ADC_NbrOfChannel = 1;
    ADC_Init(ADC1, &ADC_InitStructure);
    ADC_Cmd(ADC1, ENABLE);
    printf("Enable ADC\r\n");

    return;
}

uint32_t VSNS_Read() {
    ADC_RegularChannelConfig(ADC1, ADC_Channel_4, 1, ADC_SampleTime_11Cycles);
    ADC_SoftwareStartConvCmd(ADC1, ENABLE);
    while(!ADC_GetFlagStatus(ADC1, ADC_FLAG_EOC));
    uint32_t vin = ADC_GetConversionValue(ADC1);
    //vbus = (vin/2^12)*3300mV/4PGA/30kohm*(180+30)kohm
#if(!defined __riscv_mul || defined FORCE_SOFTMUL)
    uint32_t result = vin + (vin << 2);
    result = result + (result << 3);
    result = vin + (result << 3);
    result = result >> 8;
#else
    uint32_t result = (vin * 5775) >> 12;
#endif
    return result;
}

//pre malloced buffer
__attribute__ ((aligned(4))) uint8_t PD_Rx_Buf[34]; /* PD receive buffer */
__attribute__ ((aligned(4))) uint8_t PD_Tx_Buf[34]; /* PD send buffer */

pd_state_t* USBPD_FSM;

void GPIO_Toggle_INIT() {
    RCC_APB2PeriphClockCmd(RCC_APB2Periph_GPIOA, ENABLE);
    GPIO_OUT_INIT(GPIOA, GPIO_Pin_1, Bit_SET); //TYPEC_VEN#
    GPIO_OUT_INIT(GPIOA, GPIO_Pin_3, Bit_SET); //TYPEC_SEL#

    RCC_APB2PeriphClockCmd(RCC_APB2Periph_GPIOB, ENABLE);
    GPIO_OUT_INIT(GPIOB, GPIO_Pin_3, Bit_SET); //TYPEC_EN#
    GPIO_OUT_INIT(GPIOB, GPIO_Pin_11, Bit_SET); //TYPEC_VCONN1
    GPIO_OUT_INIT(GPIOB, GPIO_Pin_12, Bit_SET); //TYPEC_VCONN2

    printf("Enable GPIO\r\n");
    return;
}

void GPIO_Toggle_VBUS(int state){
    printf("Toggle VBUS %s\r\n", state ? "ON" : "OFF");
    GPIO_WriteBit(GPIOA, GPIO_Pin_1, state ? Bit_RESET : Bit_SET);
    return;
}

void GPIO_Toggle_VCONN(int state){
    printf("Toggle VCONN %s\r\n", state > 0 ? "ON" : "OFF");
    if(state > 2) assert("Bad VCONN Toggle Pin");
    GPIO_WriteBit(GPIOB, GPIO_Pin_11, state & 0x2 ? Bit_RESET : Bit_SET); //TYPEC_VCONN1
    GPIO_WriteBit(GPIOB, GPIO_Pin_12, state & 0x1 ? Bit_RESET : Bit_SET); //TYPEC_VCONN2
    return;
}

void GPIO_Toggle_DPSEL(int state){
    int sel = state ^ ((USBPD->CONFIG & CC_SEL) > 0);
    printf("Toggle DP MUX %s\r\n", sel ? "Flip" : "Normal");
    GPIO_WriteBit(GPIOA, GPIO_Pin_3, sel); //TYPEC_SEL#
    return;
}

void GPIO_Toggle_DPSIG(int state){
    printf("Toggle DP SIGNAL %s\r\n", state ? "ON" : "OFF");
    GPIO_WriteBit(GPIOB, GPIO_Pin_3, state ? Bit_RESET : Bit_SET); //TYPEC_EN#
    return;
}

void GPIO_PD_INIT() {
    RCC_APB2PeriphClockCmd(RCC_APB2Periph_GPIOC, ENABLE);               /* Open PD I/O clock, AFIO clock and PD clock */
    RCC_APB2PeriphClockCmd(RCC_APB2Periph_AFIO, ENABLE);
    RCC_AHBPeriphClockCmd(RCC_AHBPeriph_USBPD, ENABLE);
    GPIO_IN_INIT(GPIOC, GPIO_Pin_14 | GPIO_Pin_15);
    return;
}

void PD_FSM_Reset(pd_state_t* PD_Ctl) {   
    PD_Ctl->PD_Role = ROLE_DFP;
    PD_Ctl->PR_Role = ROLE_SRC;

    PD_Ctl->Msg_ID = 0; 
    PD_Ctl->Det_Cnt = 0;
    PD_Ctl->Cap_Cnt = 0;

    PD_Ctl->Connect = DISCONNECTED;

    PD_Ctl->Status = STA_DISCONNECT;
    PD_Ctl->VDM_Status = STA_VDM_IDLE;

    PD_Ctl->IRQ_func = NULL;
    PD_Ctl->IRQ_ret = 0;

    PD_Ctl->DP_Status.Pos = 0;
    PD_Ctl->DP_Status.Link = 0;
    PD_Ctl->DP_Status.Enabled = DISABLE;
    PD_Ctl->DP_Status.Trained = 0;
    return;
}

void PD_PHY_Reset(pd_state_t* PD_Ctl) {
    GPIO_Toggle_VCONN(RESET);
    GPIO_Toggle_VBUS(RESET);
    PD_FSM_Reset(PD_Ctl);
    return;
}

void PD_INIT(pd_state_t* PD_Ctl) {
    printf("Enable USBPD\r\n");
    GPIO_PD_INIT();
    GPIO_Toggle_INIT();

    AFIO->CTLR |= USBPD_IN_HVT | USBPD_PHY_V33;
    USBPD->PORT_CC1 = CC_CMP_45 | CC_PU_180; //180 for 1A5
    USBPD->PORT_CC2 = CC_CMP_45 | CC_PU_180; //180 for 1A5

    PD_Ctl->Rx_Buf = PD_Rx_Buf;
    PD_Ctl->Tx_Buf = PD_Tx_Buf;
    USBPD->CONFIG = PD_DMA_EN;
    USBPD->STATUS = BUF_ERR | IF_RX_BIT | IF_RX_BYTE | IF_RX_ACT | IF_RX_RESET | IF_TX_END;

    NVIC_InitTypeDef NVIC_InitStructure = {0};
    NVIC_InitStructure.NVIC_IRQChannel = USBPD_IRQn;
    NVIC_InitStructure.NVIC_IRQChannelPreemptionPriority = 0;
    NVIC_InitStructure.NVIC_IRQChannelSubPriority = 0;
    NVIC_Init(&NVIC_InitStructure);
    USBPD_FSM = PD_Ctl;
    PD_FSM_Reset(PD_Ctl);

    USBPD->CONFIG |= PD_ALL_CLR;
    USBPD->CONFIG &= ~PD_ALL_CLR;
    USBPD->CONTROL &= ~PD_TX_EN;
    USBPD->DMA = (uint32_t)PD_Ctl->Rx_Buf;
    USBPD->BMC_CLK_CNT = UPD_TMR_RX_24M;
    USBPD->CONTROL |= BMC_START;

    return;
}

static void PD_Load_Header(uint8_t type, pd_state_t* PD_Ctl) {
    /* Message Header
       BIT15 - Extended;
       BIT[14:12] - Number of Data Objects
       BIT[11:9] - Message ID
       BIT8 - Port Power Role/Cable Plug, 0: SINK; 1: SOURCE;
       BIT[7:6] - Revision, 00: V1.0; 01: V2.0; 10: V3.0;
       BIT5 - Port Data Role, 0: UFP; 1: DFP;
       BIT[4:0] - Message Type
    */
    uint16_t data = type & 0x1f;
    data |= 0x40; //PD 2.0
    if(PD_Ctl->PD_Role) {
        data |= 0x20;
    }
    if(PD_Ctl->PR_Role) {
        data |= 0x100;
    }
    data |= PD_Ctl->Msg_ID << 9;
    ((uint16_t*)PD_Ctl->Tx_Buf)[0] = data;
    return;
}

static void PD_Load_Header_ID(uint8_t type, uint8_t id, pd_state_t* PD_Ctl) {
    uint16_t data = type & 0x1f;
    data |= 0x40; //PD 2.0
    if(PD_Ctl->PD_Role) {
        data |= 0x20;
    }
    if(PD_Ctl->PR_Role) {
        data |= 0x100;
    }
    data |= id << 9;
    ((uint16_t*)PD_Ctl->Tx_Buf)[0] = data;
    return;
}

static void PD_Load_DataObj(void* data, size_t len, pd_state_t* PD_Ctl) {
    if((len & 3) != 0) {
        char str[64];
        __builtin_sprintf(str, "Misalign of PDO with length %d", len);
        assert(str);
    }
    ((uint8_t*)(PD_Ctl->Tx_Buf))[1] |= len << 2; //Load data size into header
    __builtin_memcpy(PD_Ctl->Tx_Buf + 2, data, len);
    return;
}

static void PD_Load_VDM(uint16_t svid, int cmd, void* buf, pd_state_t* PD_Ctl) {
    //see description above.
    uint32_t data = cmd & 0x1F;
    data |= DEF_CMDTYPE_INIT << 6;
    data |= 0x8000; //Structured VDM
    data |= svid << 16;
    ((uint32_t*)buf)[0] = data;
    return;
}

static void PD_Load_VDM_POS(uint8_t pos, void* buf, pd_state_t* PD_Ctl) {
    if(!pos) assert("Empty VDO Pos");
    ((uint32_t*)buf)[0] |= pos << 8;
    return;
}

static void PD_Load_VDM_CMDTYPE(uint8_t cmdtype, void* buf, pd_state_t* PD_Ctl) {
    ((uint32_t*)buf)[0] |= cmdtype << 6;
    return;
}

static void PD_Load_VDM_DP_S(void* buf, pd_state_t* PD_Ctl) {
    //see description above.
    uint32_t data = 0x1;
    ((uint32_t*)buf)[1] = data;
    return;
}

int PD_DP_Pin_Decider(dp_status_t info) {
    int mode = info.Receptable ? info.UFP_Pin : info.DFP_Pin;
    printf("assign: 0x%02x\r\n", mode);
    if(mode & BIT(2)) return BIT(2); //Assignment C
    if(mode & BIT(4)) return BIT(4); //Assignment E
    return BIT(2);
}

static void PD_Load_VDM_DP_CFG(void* buf, pd_state_t* PD_Ctl) {
    /* DisplayPort Capability
        BIT[31:16] - Reserved
        BIT[15:8] - Configure UFP_U Pin Assignment
            00000000 = De-select pin assignment.
            00000001 = Select Pin Assignment A
            00000010 = Select Pin Assignment B
            00000100 = Select Pin Assignment C
            00001000 = Select Pin Assignment D
            00010000 = Select Pin Assignment E
            00100000 = Select Pin Assignment F
            Pin assignments A, B, and F have been deprecated.
        BIT[7:6] - Reserved
        BIT[5:2] - Signaling for Transport of DisplayPort Protocol
            0: USB; 1: DP1.3;
        BIT[1:0] - Select Configuration
            00 = Set configuration for USB
            01 = Set configuration for UFP_U as DFP_D
            10 = Set configuration for UFP_U as UFP_D
            11 = Reserved
    */
    GPIO_Toggle_DPSEL(FLIP_SEL);
    uint32_t data = 0x2 | (0x1 << 2) | (PD_DP_Pin_Decider(PD_Ctl->DP_Status) << 8); //Set UFP_U as UFP_D and Enable DP1.3 Signaling
    ((uint32_t*)buf)[1] = data;
    return;
}

void PD_Send(void* buf, size_t len, int sop) {
    USBPD->PORT_CC1 |= CC_LVE;
    USBPD->PORT_CC2 |= CC_LVE;

    USBPD->TX_SEL = sop;
    USBPD->BMC_TX_SZ = len;
    uint32_t rx = USBPD->DMA;
    USBPD->DMA = (uint32_t)buf;

    USBPD->STATUS &= BMC_AUX_INVALID;
    USBPD->BMC_CLK_CNT = UPD_TMR_TX_24M;
    USBPD->CONTROL |= PD_TX_EN;
    USBPD->CONTROL |= BMC_START;

    while((USBPD->STATUS & IF_TX_END) == 0);
    USBPD->STATUS |= IF_TX_END;

    USBPD->PORT_CC1 &= ~CC_LVE;
    USBPD->PORT_CC2 &= ~CC_LVE;

    USBPD->CONFIG |= PD_ALL_CLR;
    USBPD->CONFIG &= ~PD_ALL_CLR;
    USBPD->CONTROL &= ~PD_TX_EN;
    USBPD->DMA = rx;
    USBPD->BMC_CLK_CNT = UPD_TMR_RX_24M;
    USBPD->CONTROL |= BMC_START;
    return;
}

void PD_Send_Rst() {
    PD_Send(NULL, 0, UPD_HARD_RESET);
    return;
}

size_t PD_Recv() {
    for(int i = 0; i < 250; i++) {
        if((USBPD->STATUS & IF_RX_ACT) == IF_RX_ACT) {
            size_t len = USBPD->BMC_BYTE_CNT;
            USBPD->STATUS |= IF_RX_ACT;
            return len;
        }
        TIM_Delay(4);
    } //1ms tReceive for GoodCRC
    return 0;
}

int PD_Send_Retry(uint8_t type, void* data, size_t len, pd_state_t* PD_Ctl) {
    //Load Data Structure
    PD_Load_Header(type, PD_Ctl);
    PD_Load_DataObj(data, len, PD_Ctl);
    //Retry for 3 times
    for(int retry = 0; retry < 3; retry++) {
        PD_Send(PD_Ctl->Tx_Buf, len + 2, UPD_SOP0);
        int size = PD_Recv();
        if(size == 0) continue;
        if((size == 6) && 
            (PD_PARSE_TYPE(PD_Ctl->Rx_Buf) == DEF_TYPE_GOODCRC) && 
            (PD_PARSE_MSGID(PD_Ctl->Rx_Buf) == PD_Ctl->Msg_ID)) {
            PD_Ctl->Msg_ID = (PD_Ctl->Msg_ID + 1) & 0x07;
            return 0;
        }
        TIM_Delay_Us(20);
    }
    return -1;
}

int PD_Send_Retry_Rst(uint8_t type, void* data, size_t len, pd_state_t* PD_Ctl) {
    if(PD_Send_Retry(type, data, len, PD_Ctl)) {
        if(PD_Send_Retry(DEF_TYPE_SOFT_RESET, NULL, 0, PD_Ctl)) {
            PD_Send_Rst();
            PD_PHY_Reset(PD_Ctl);
            return -1;
        }
        PD_FSM_Reset(PD_Ctl);
        return -1;
    }
    return 0;
}

int PD_Recv_Retry(uint8_t type, int timeout, pd_state_t* PD_Ctl) {
    for(int i = 0; i < timeout; i++) {
        int size = PD_Recv(); //1ms
        if(size && (PD_PARSE_TYPE(PD_Ctl->Rx_Buf) == type)) {
            TIM_Delay_Us(20);
            PD_Load_Header_ID(DEF_TYPE_GOODCRC, PD_PARSE_MSGID(PD_Ctl->Rx_Buf), PD_Ctl);
            PD_Send(PD_Ctl->Tx_Buf, 2, UPD_SOP0);
            return 0;
        }
    }
    return -1;
}

void PD_Enter_ListenMode(pd_state_t* PD_Ctl) {
    PD_Ctl->IRQ_ret = 0;
    USBPD->CONFIG |= IE_RX_ACT | IE_RX_RESET;
    NVIC_EnableIRQ(USBPD_IRQn);
    return;
}

void PD_Exit_ListenMode(pd_state_t* PD_Ctl) {
    USBPD->CONFIG &= ~(IE_RX_ACT | IE_RX_RESET);
    NVIC_DisableIRQ(USBPD_IRQn);
    PD_Ctl->IRQ_ret = 0;
    return;
}

void USBPD_IRQHandler(void) __attribute__((interrupt("WCH-Interrupt-fast")));
void USBPD_IRQHandler() {
    //RESET Process
    if(USBPD_FSM == NULL) {
        assert("USBPD IRQ Handler NULL Pointer Exception");
        return;
    }
    if(USBPD->STATUS & IF_RX_RESET) {
        USBPD->STATUS |= IF_RX_RESET;
        PD_PHY_Reset(USBPD_FSM);
        USBPD_FSM->IRQ_ret = 1;
        printf("A unexpected Hard Reset was occured from UFP\r\n");
        return;
    }
    if(USBPD->STATUS & IF_RX_ACT) {
        USBPD->STATUS |= IF_RX_ACT;
        size_t len = USBPD->BMC_BYTE_CNT;
        TIM_Delay_Us(20);
        PD_Load_Header_ID(DEF_TYPE_GOODCRC, PD_PARSE_MSGID(USBPD_FSM->Rx_Buf), USBPD_FSM);
        PD_Send(USBPD_FSM->Tx_Buf, 2, UPD_SOP0);
        if(USBPD_FSM->IRQ_func) {
            int (*Handler)(size_t, pd_state_t*) = USBPD_FSM->IRQ_func;
            NVIC_DisableIRQ(USBPD_IRQn);
            USBPD_FSM->IRQ_ret = Handler(len, USBPD_FSM);
            NVIC_EnableIRQ(USBPD_IRQn);
        }
    }
    return;
}

void PD_Connect(int passive, int ccpin, pd_state_t* PD_Ctl) {
    PD_Ctl->Connect = CONNECTED;
    PD_Ctl->Status = STA_SINK_CONNECT;
    if(ccpin == 1) {
        USBPD->CONFIG &= ~CC_SEL;   //CC1
    } else { //attach == 2
        USBPD->CONFIG |= CC_SEL;    //CC2
    }
    printf("PD Connect at CC%d\r\n", ccpin);
    GPIO_Toggle_VBUS(SET);
    PD_Ctl->Timer = TIM_GetTimer(); //Delay Start from VBUS ON
    if(!passive) {
        GPIO_Toggle_VCONN(ccpin);
    }
    return;
}

void PD_Disconnect(pd_state_t* PD_Ctl) {
    PD_Ctl->Connect = DISCONNECTED;
    PD_Ctl->Status = STA_DISCONNECT;
    PD_PHY_Reset(PD_Ctl);
    printf("PD Disconnect\r\n");
    return;
}

static int PD_TestCC() {
    /* return:
        000: Nothing Attached
        001: Passive at CC1
        010: Passive at CC2
        011: Debug Accessory Mode
        100: Audio Adapter Accessory Mode / with Powered cable plugged but without Sink attached
        101: Active at CC1
        110: Active at CC2
        111: **Unreachable**
    */
    int Rd = (GPIOC->INDR & (PIN_CC1 | PIN_CC2)) >> 14;
    int Ra = ((USBPD->PORT_CC2 & PA_CC_AI) << 1) | (USBPD->PORT_CC1 & PA_CC_AI);
    return ((Ra < 3) << 2) | (Ra & (Rd ^ 3));
}

int PD_Detect(pd_state_t* PD_Ctl) {
    int state = PD_TestCC();
    int ccpin = state & 3;
    int passive = state < 4;
    if(PD_Ctl->Connect) {
        if (ccpin) {
            PD_Ctl->Det_Cnt = 0;
            return 0;
        } else {
            PD_Ctl->Det_Cnt++;
            if(PD_Ctl->Det_Cnt == 5) {
                PD_Ctl->Det_Cnt = 0;
                PD_Disconnect(PD_Ctl);
                BC_Disconnect(&PD_Ctl->BC_Ctl);
            }
            return -1;
        }
    } else {
        if (!ccpin) {
            PD_Ctl->Det_Cnt = 0;
            return 0;
        } else {
            PD_Ctl->Det_Cnt++;
            if(PD_Ctl->Det_Cnt == 5) {
                PD_Ctl->Det_Cnt = 0;
                PD_Connect(passive, ccpin, PD_Ctl);
                BC_Connect(&PD_Ctl->BC_Ctl);
                return 0;
            }
            return -1;
        }
    }
}

int PD_Delay(unsigned int ms, pd_state_t* PD_Ctl) {
    timer_t next_timer = PD_Ctl->Timer + ms*(SystemCoreClock/8000);
    PD_Enter_ListenMode(PD_Ctl);
    while(!TIM_Timeout(next_timer)) {
        __WFI();
        if(PD_Ctl->IRQ_ret) {
            PD_Exit_ListenMode(PD_Ctl);
            return -1;
        }
    }
    PD_Exit_ListenMode(PD_Ctl);
    PD_Ctl->Timer = TIM_GetTimer(); 

    while(PD_Detect(PD_Ctl)) TIM_Delay_Us(1000);
    if(PD_Ctl->Status == STA_DISCONNECT) return -1;

    return 0;
}

int PD_SendRecv_VDM(int cmd, int timeout, void* data, size_t len, pd_state_t* PD_Ctl) {
    if(PD_Send_Retry_Rst(DEF_TYPE_VENDOR_DEFINED, data, len, PD_Ctl)) return -1;
    PD_Ctl->Timer = TIM_GetTimer();
    for(int i = 0; i < 5; i++) {
        do {
            if(PD_Recv_Retry(DEF_TYPE_VENDOR_DEFINED, timeout, PD_Ctl)) return -1;
        } while(PD_PARSE_CMD(PD_Ctl->Rx_Buf) != cmd);
        if(PD_PARSE_CMDTYPE(PD_Ctl->Rx_Buf) == DEF_CMDTYPE_ACK) return 0;
        if(PD_PARSE_CMDTYPE(PD_Ctl->Rx_Buf) == DEF_CMDTYPE_NAK) return -1;
        if(PD_Delay(50, PD_Ctl)) return -1;
    }
    //run out of nBusyCount
    return -1;
}

static int PD_Test_IDENT(pd_state_t* PD_Ctl) {
    pd_vdo_ident_t vdo;
    
    int len = PD_PARSE_SIZE(PD_Ctl->Rx_Buf) - 1;
    __builtin_memcpy(&vdo, PD_Ctl->Rx_Buf + 6, 4 * len);
    //WCH can make SOP into buffer with header to form a 4-byte alignment which is well for struct operation.

    printf("VDM Info:\r\n");
    printf("VID: 0x%04x\r\n", PD_PARSE_USB_VID(vdo.id_header));
    printf("PID: 0x%04x\r\n", PD_PARSE_PROD_ID(vdo.product));
    printf("bcd: 0x%04x\r\n", PD_PARSE_PROD_BCD(vdo.product));
    printf("prod_type: %d\r\n", PD_PARSE_PROD_TYPE(vdo.id_header));
    printf("is_ama: %d\r\n", PD_PARSE_PROD_TYPE(vdo.id_header) == 0x05);
    printf("usb_host: %d\r\n", PD_PARSE_USB_HOST(vdo.id_header));
    printf("usb_device: %d\r\n", PD_PARSE_USB_DEVICE(vdo.id_header));
    printf("modal: %d\r\n", PD_PARSE_MODAL(vdo.id_header));
    printf("xid: 0x%08x\r\n", vdo.cert_state);

    if(!PD_PARSE_MODAL(vdo.id_header)) return -1;

    if(PD_PARSE_PROD_TYPE(vdo.id_header) != 0x05) return 0; //Alternate Mode Adapter
    if(len < 4) return 0;
    printf("AMA Info:\r\n");
    printf("hw_ver: 0x%04x\r\n", PD_PARSE_HW_VER(vdo.product_type));
    printf("fw_ver: 0x%04x\r\n", PD_PARSE_FW_VER(vdo.product_type));
    printf("vbus_req: %d\r\n", PD_PARSE_USB_VBUS(vdo.product_type));
    printf("vconn_req: %d\r\n", PD_PARSE_USB_VCONN(vdo.product_type));
    printf("vconn_watt: %d\r\n", PD_PARSE_VCONN_WATT(vdo.product_type));
    printf("usbss_sig: %d\r\n", PD_PARSE_USBSS_SIG(vdo.product_type));
    printf("usbss_dir: 0x%02x\r\n", PD_PARSE_USBSS_DIR(vdo.product_type));

    if(!PD_PARSE_USB_VCONN(vdo.product_type)) GPIO_Toggle_VCONN(RESET);
    return 0;
}

static int PD_Test_SVID(pd_state_t* PD_Ctl) {
    uint16_t* svid = PD_Ctl->Rx_Buf + 2;
    for(int i = 0; i < 12; i++) {
        int pos = i ^ 1; //weirdo big endian whin whole PD's little endian stuffs...
        if(svid[pos] == DEF_SVID_EOF) return -1;
        if(svid[pos] == DEF_SVID_DISPLAYPORT) return 0;
    }
    return 1;
}

static int PD_Test_MODE(pd_state_t* PD_Ctl) {
    uint32_t mode[6];

    int len = PD_PARSE_SIZE(PD_Ctl->Rx_Buf) - 1;
    __builtin_memcpy(mode, PD_Ctl->Rx_Buf + 6, 4*len);

    for(int i = 0; i < len; i++) {
        printf("MODE %d:\r\n", i + 1);
        /* PD_PARSE_DP_CAP
            00 = Reserved
            01 = UFP_D(DP Sink Device) capable, including Branch Device
            10 = DFP_D(DP Source Device) capable, including Branch Device
            11 = Both DFP_D and UFP_D capable
        */
        printf("capability: %d\r\n", PD_PARSE_DP_CAP(mode[i]));
        printf("receptable: %d\r\n", PD_PARSE_RECEPTACLE(mode[i]));
        printf("supported_pin: 0x%02x\r\n", PD_PARSE_DFP_PIN(mode[i]));
    }
    
    for(int i = 0; i < len; i++) {
        if(!PD_PARSE_DP_SIG(mode[i])) continue;
        if(!PD_PARSE_DP_CAP_UFP_D(mode[i])) continue;
        printf("DP MODE %d is used\r\n", i + 1);
        PD_Ctl->DP_Status.Pos = i + 1;
        PD_Ctl->DP_Status.DFP_Pin = PD_PARSE_DFP_PIN(mode[i]);
        PD_Ctl->DP_Status.UFP_Pin = PD_PARSE_UFP_PIN(mode[i]);
        PD_Ctl->DP_Status.Receptable = PD_PARSE_RECEPTACLE(mode[i]);
        return 0;
    }
    return -1;
}

static int PD_Test_DP_S(pd_state_t* PD_Ctl) {
    uint16_t* data = PD_Ctl->Rx_Buf + 6;
    uint32_t status = (data[1] << 16) | data[0];
    PD_Ctl->DP_Status.Link = status;

    printf("DP Link Info:\r\n");
    /* PD_PARSE_DP_STA, inconsistency with previous PD_PARSE_DP_CAP one...
        00 = neither DFP_D nor UFP_D connected or adapter is disabled
        01 = DFP_D Connected
        10 = UFP_D Connected
        11 = Both DFP_D and UFP_D Connected
    */
    printf("enabled: %d\r\n", PD_PARSE_DP_ENABLED(status));
    printf("connected: %d\r\n", PD_PARSE_DP_STA(status));
    printf("low_power: %d\r\n", PD_PARSE_DP_LP(status));
    printf("multi_func: %d\r\n", PD_PARSE_DP_MUL(status));
    printf("hpd: %d\r\n", PD_PARSE_DP_HPD(status));
    printf("irq: %d\r\n", PD_PARSE_DP_IRQ(status));
    printf("usb_req: %d\r\n", PD_PARSE_DP_USB(status));
    printf("exit_req: %d\r\n", PD_PARSE_DP_EXIT(status));

    if(!PD_PARSE_DP_ENABLED(status)) return -1;
    if(!PD_PARSE_DP_STA_UFP_D(status)) return -1;
    return 0;
}
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
int main() {
    SYS_INIT();
    VSNS_INIT();
    WS2812_INIT();
#ifndef NO_MPD
    IIC_Init();
    MPD_Init();
#endif
    pd_state_t PD_Ctl;
    PD_INIT(&PD_Ctl);
    BC_INIT(&PD_Ctl.BC_Ctl);
    EXTI_INIT();
    while(1) {
        if(!PD_Detect(&PD_Ctl)) PD_Proc(&PD_Ctl);
        else TIM_Delay_Us(20);
    }
    __builtin_unreachable();
    return 0;
}

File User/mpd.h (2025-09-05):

#ifndef __MPD_H
#define __MPD_H

#define BIT(x)          (1 << (x))

#define MPD_DEV_ADR     0x68    //7b1101000
#define MPD_REFCLK      REF_FREQ_26M

//Phy
#define MPD_2LANE
#define MPD_BW          DP_SRCCTRL_BW27
#define MPD_SWG         DP_SWG_0P4
#define MPD_PRE         DP_PRE_0

//Test Pattern
#define MPD_TEST        COLOR_BAR
#define MPD_TEST_COLOR  0x114514
#define MPD_PXLPARAM    0x01130111

//Video Format
#define MPD_DP_BPP      OPXLFMT_RGB888
#define MPD_DPI_POL     VS_POL_ACTIVE_LOW | HS_POL_ACTIVE_LOW | DE_POL_ACTIVE_HIGH
#define MPD_DPI_FMT     SUB_CFG_TYPE_CONFIG1
#define MPD_DPI_BPP     DPI_BPP_RGB888

//Video Timing Variable
#define MPD_HPW         44
#define MPD_HBPR        148
#define MPD_Hactive     1920
#define MPD_HFPR        88
#define MPD_VPW         5
#define MPD_VBPR        36
#define MPD_Vactive     1080
#define MPD_VFPR        4

//Audio
#define MPD_AUDIO
#define MPD_AUDIO_FS        MPD_AUD_FS48
#define MPD_AUDIO_WIDTH     MPD_AUD_WIDTH16
#define MPD_AUDIO_FMT       MPD_AUD_FMT_STD

/* Internal Macro */

#ifdef MPD_AUDIO
#define MPD_AUDSRC   DP0_AUDSRC_I2S_RX
#else
#define MPD_AUDSRC   DP0_AUDSRC_NO_INPUT
#endif

#ifdef MPD_2LANE
#define MPD_LANES       2
#else
#define MPD_LANES       1
#endif

#ifdef MPD_TEST
#define MPD_TEST_MODE   MPD_TEST
#else
#define MPD_TEST_MODE   0
#endif

#define INTCTL_G    0x0560
#define INTSTS_G    0x0564
#define INT_SYSERR  BIT(16)

#define DPIPXLFMT   0x0440
#define VS_POL_ACTIVE_LOW		(1 << 10)
#define VS_POL_ACTIVE_HIGH		(0 << 10)
#define HS_POL_ACTIVE_LOW		(1 << 9)
#define HS_POL_ACTIVE_HIGH		(0 << 9)
#define DE_POL_ACTIVE_LOW		(1 << 8)
#define DE_POL_ACTIVE_HIGH		(0 << 8)
#define SUB_CFG_TYPE_CONFIG1	(0 << 2) /* LSB aligned */
#define SUB_CFG_TYPE_CONFIG2	(1 << 2) /* Loosely Packed */
#define SUB_CFG_TYPE_CONFIG3	(2 << 2) /* LSB aligned 8-bit */
#define DPI_BPP_RGB888			(0 << 0)
#define DPI_BPP_RGB666			(1 << 0)
#define DPI_BPP_RGB565			(2 << 0)

#define VPCTRL0		0x0450
#define VSDELAY(x)	((x) << 20)
#define OPXLFMT_RGB666		(0 << 8)
#define OPXLFMT_RGB888		(1 << 8)
#define FRMSYNC_DISABLED	(0 << 4) /* Video Timing Gen Disabled */
#define FRMSYNC_ENABLED		(1 << 4) /* Video Timing Gen Enabled */
#define MSF_DISABLED		(0 << 0) /* Magic Square FRC disabled */
#define MSF_ENABLED			(1 << 0) /* Magic Square FRC enabled */

#define VP_TIM			0x0454
#define VFUEN0			0x0464
#define VFUEN           BIT(0)

#define TC_IDREG		0x0500
#define SYSBOOT			0x0504
#define SYSSTAT			0x0508
#define SYSRSTENB		0x050c
#define ENBI2C          BIT(0)
#define ENBLCD0         BIT(2)
#define ENBBM           BIT(3)
#define ENBDSIRX        BIT(4)
#define ENBREG          BIT(5)
#define ENBHDCP         BIT(8)
#define SYSCTRL			0x0510
#define DP0_OSCLK_AVALIABLE     (1 << 11)
#define DP0_AUDSRC_NO_INPUT		(0 << 3)
#define DP0_AUDSRC_I2S_RX		(1 << 3)
#define DP0_VIDSRC_NO_INPUT		(0 << 0)
#define DP0_VIDSRC_DSI_RX		(1 << 0)
#define DP0_VIDSRC_DPI_RX		(2 << 0)
#define DP0_VIDSRC_COLOR_BAR	(3 << 0)

#define DP0CTL			0x0600
#define VID_MN_GEN		BIT(6)      /* Auto-generate M/N values */
#define AUD_MN_GEN      BIT(7)      /* Auto-generate M/N values */
#define EF_EN			BIT(5)      /* Enable Enhanced Framing */
#define AUD_EN			BIT(2)      /* Video transmission enable */
#define VID_EN			BIT(1)      /* Video transmission enable */
#define DP_EN			BIT(0)      /* Enable DPTX function */
#ifdef MPD_2LANE
#define DP_PHY_CTRL_EN  BGREN | PWR_SW_EN | PHY_2LANE | PHY_A0_EN | PHY_M0_EN
#else
#define DP_PHY_CTRL_EN  BGREN | PWR_SW_EN | PHY_A0_EN | PIEC60958_HY_M0_EN
#endif

#define DP0_VIDMNGEN0	    0x0610	/* DP0 Video Force M Value Register */
#define DP0_VIDMNGEN1	    0x0614	/* DP0 Video Force N Value Register */
#define DP0_VMNGENSTATUS	0x0618	/* DP0 Video Current M Value Register */
#define DP0_AUDMNGEN0		0x0628	/* DP0 Audio Force M Value Register */
#define DP0_AUDMNGEN1		0x062c	/* DP0 Audio Force N Value Register */
#define DP0_AMNGENSTATUS	0x0630	/* DP0 Audio Current M Value Register */

#define DP0_SECSAMPLE	0x0640
#define DP0_TIM         0x0644

#define DP0_MISC		0x0658
#define MAX_TU_SYMBOL(x)    ((x) << 23)
#define TU_SIZE(x)		    ((x) << 16)

#define FMT_SRGB        (4 << 1)
#define FMT_ARGB        (12 << 1)
#define FMT_YUV422      (13 << 1)
#define FMT_YUV444      (14 << 1)

#if(MPD_DP_BPP == OPXLFMT_RGB888)
#define BPC             (1 << 5) //BPC_8
#else
#define BPC				(0 << 5) //BPC_6
#endif
#define MISC0_ASYNC_CLK     0
#define MISC0_SYNC_CLK      BIT(0)

#define DP0_AUXCFG0		0x0660
#define DP0_AUXCFG1		0x0664
#define DP0_AUXADDR		0x0668

#define DP0_AUXWDATA    0x066c
#define DP0_AUXRDATA    0x067c
#define DP0_AUXSTATUS	0x068c

#define DP0_LTSTAT		    0x06d0
#define LT_LOOPDONE			BIT(13)

#define DP0_SNKLTCHGREQ		0x06d4
#define DP0_LTLOOPCTRL		0x06d8

#define DP0_SNKLTCTRL		0x06e4

#define DP0_TPATDAT0		0x06e8	    /* DP0 Test Pattern bits 29 to 0 */
#define DP0_TPATDAT1		0x06ec	    /* DP0 Test Pattern bits 59 to 30 */
#define DP0_TPATDAT2		0x06f0	    /* DP0 Test Pattern bits 89 to 60 */
#define DP0_TPATDAT3		0x06f4	    /* DP0 Test Pattern bits 119 to 90 */

#define AUDCFG0			0x0700	/* DP0 Audio Config0 Register */
#define AUDCFG1			0x0704	/* DP0 Audio Config1 Register */
#define AUDIFDATA0		0x0708	/* DP0 Audio Info Frame Bytes 3 to 0 */
#define AUDIFDATA1		0x070c	/* DP0 Audio Info Frame Bytes 7 to 4 */
#define AUDIFDATA2		0x0710	/* DP0 Audio Info Frame Bytes 11 to 8 */
#define AUDIFDATA3		0x0714	/* DP0 Audio Info Frame Bytes 15 to 12 */
#define AUDIFDATA4		0x0718	/* DP0 Audio Info Frame Bytes 19 to 16 */
#define AUDIFDATA5		0x071c	/* DP0 Audio Info Frame Bytes 23 to 20 */
#define AUDIFDATA6		0x0720	/* DP0 Audio Info Frame Bytes 27 to 24 */
#define AUD_MUTE        BIT(24)
#define AUD_STEREO      BIT(8)
#define AUD_MONO        0

#define MPD_AUD_FS32        1
#define MPD_AUD_FS44P1      2
#define MPD_AUD_FS48        3
#define MPD_AUD_FS88P2      4
#define MPD_AUD_FS96        5
#define MPD_AUD_FS176P4     6
#define MPD_AUD_FS192       7

#define MPD_AUD_WIDTH16     1
#define MPD_AUD_WIDTH20     2
#define MPD_AUD_WIDTH24     3
#if (MPD_AUDIO_WIDTH == MPD_AUD_WIDTH16)
#define MPD_I2S_BIT     16
#elif (MPD_AUDIO_WIDTH == MPD_AUD_WIDTH20)
#define MPD_I2S_BIT     20
#elif (MPD_AUDIO_WIDTH == MPD_AUD_WIDTH24)
#define MPD_I2S_BIT     24
#endif

//Secondary-data Packet Type
#define AUD_PKT_ID      170 //refer to excel sheet(?) FIXME
#define AUD_IF_TYPE     0x84    //CEA-861-E InfoFrame, 0x80 + 0x04(Audio InfoFrame)

#define AUD_CC          1   //2 Channels
#define AUD_CT          1   //PCM

#define AUD_SS          MPD_AUDIO_WIDTH //1:16 bits 2:20bits 3:24bits
#define AUD_SF          MPD_AUDIO_FS    //1:32kHz 2:44.1kHz 3:48kHz 4:88.2kHz 5:96kHz 6:176.4kHz 7:192kHz

#define AUD_CXT         0   //Audio Codec Extension, no need for PCM

#define AUD_CA          0   //Audio Channel Assignment, except zero is invalid for stereo
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

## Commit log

2025-02-15 fix some known issues.
    [main.c]
2025-03-03 submit EVB PCB project.
    [cover.kicad_sch, license.kicad_sch, pdaltmode.kicad_pcb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]
2025-03-03 add assembly pdf.
2025-03-04 DFM ECO.
    [pdaltmode.kicad_pcb]
2025-03-04 Sigrity ECO.
    [pdaltmode.kicad_pcb]
2025-03-12 update v0.2.
    [cover.kicad_sch, pdaltmode.kicad_pcb, pdaltmode.kicad_sch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]
2025-03-17 clean useless file.
    [pdaltmode.kicad_pcb]
2025-03-17 remove kicad_prl file.
2025-03-19 cleaning code.
    [pdaltmode.kicad_pcb]
2025-03-20 upload 3d step model
    [pdaltmode.kicad_pcb]
2025-03-20 update USB-C step model
    [pdaltmode.kicad_pcb]
2025-03-22 update evb pcb files.
    [cover.kicad_sch, pdaltmode.kicad_pcb, pdaltmode.kicad_sch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]
2025-03-22 tiny gerber ECO
    [pdaltmode.kicad_pcb]
2025-03-23 update to standard USB footprint, and 0.2a revision PCB.
    [pdaltmode.kicad_pcb, port.kicad_sch]
2025-09-05 bug fixed, release version.
    [mpd.c, mpd.h]
2025-11-03 update EVB.
    [cover.kicad_sch, license.kicad_sch, pdaltmode.kicad_pcb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]
2025-11-03 clean codes.
    [pdaltmode.kicad_pcb]
2025-12-08 update schematic pdf.(however gerber and assembly are not.)
2025-12-08 remove unused empty file.
    [power.kicad_sch]
2025-12-24 tiny fixup.
    [pdaltmode.kicad_pcb, pdaltmode.kicad_sch, video.kicad_sch]

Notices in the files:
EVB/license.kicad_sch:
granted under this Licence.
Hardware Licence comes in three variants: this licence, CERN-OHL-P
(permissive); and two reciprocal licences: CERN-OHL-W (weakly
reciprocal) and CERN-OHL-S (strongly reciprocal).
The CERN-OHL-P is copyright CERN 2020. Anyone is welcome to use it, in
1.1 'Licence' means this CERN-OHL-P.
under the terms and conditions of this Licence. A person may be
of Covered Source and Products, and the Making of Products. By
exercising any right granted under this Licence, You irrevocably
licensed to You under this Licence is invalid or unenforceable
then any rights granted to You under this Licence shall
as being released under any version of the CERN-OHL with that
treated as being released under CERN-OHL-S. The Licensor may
